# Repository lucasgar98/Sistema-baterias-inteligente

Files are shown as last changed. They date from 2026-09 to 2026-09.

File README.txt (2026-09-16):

================================================================================
  SISTEMA INTELIGENTE DE CARGA, DESCARGA Y DIAGNÓSTICO DE BATERÍAS (PROYECTO)
================================================================================

Este proyecto es una plataforma integrada de hardware y software diseñada para 
realizar ciclos de carga, descarga y caracterización de baterías de múltiples 
químicas (Li-Ion, Pb, NiMH). 

El sistema combina el control de potencia en tiempo real (MicroPython), una 
interfaz táctil física (LVGL v8 en CYD), visión por computadora para 
identificación de baterías (ESP32-CAM + pyzbar) y un backend de monitoreo y 
almacenamiento (FastAPI + SQLite + InfluxDB + MQTT) orquestado en Docker.

--------------------------------------------------------------------------------
1. ARQUITECTURA GENERAL Y FLUJO DE DATOS
--------------------------------------------------------------------------------

El flujo de información y control entre los componentes se organiza así:

   [ ESP32-CAM ] -------------( WiFi: Stream MJPEG )-------------> [ FASTAPI ]
         |                                                            |
     ( UART1 )                                                   ( Escribe a DB )
         |                                                            |
         v                                                            v
  [ ESP32 MASTER ]                                            [ SQLITE / INFLUX ]
    |          |
 ( UART2 )   ( I2C / PWM / ADC )
    |          |
    v          v
 [ CYD ]     [ SENSORES (INA219/NTC) y MOSFETS DE POTENCIA ]
 
* Comunicaciones clave:
  - ESP32 Master <-> Cheap Yellow Display (CYD): UART2 a 115200 baudios.
  - ESP32 Master <-> ESP32-CAM: UART1 a 115200 baudios.
  - ESP32 Master -> Sensor de Corriente (INA219): Bus I2C.
  - ESP32 Master -> MOSFETs de potencia: Señal digital PWM.
  - FastAPI (Servidor) <-> Broker MQTT (Mosquitto): Red local TCP.

--------------------------------------------------------------------------------
2. ESTRUCTURA DEL PROYECTO (Workspace)
--------------------------------------------------------------------------------

El repositorio se organiza de la siguiente manera:

/ (Raíz del proyecto)
|-- docker-compose.yml           <- Orquestador de servicios (Mosquitto, InfluxDB, API)
|-- README.txt                   <- Esta documentación principal
|
|-- backend/                     <- Servidor backend y panel de control web
|   |-- main.py                  <- API FastAPI, cliente MQTT, base de datos y lector QR
|   |-- dockerfile               <- Archivo de construcción de imagen Docker
|   |-- baterias.db              <- Base de datos SQLite (se genera sola al arrancar)
|   `-- frontend/                <- Código del dashboard web para PC
|       `-- index.html           <- Panel de monitoreo web interactivo
|
|-- firmware/                    <- Código fuente para los microcontroladores
|   |-- esp32_master/            <- Firmware del ESP32 Principal (MicroPython)
|   |   |-- main.py              # Lógica de potencia, control PWM y lectura de sensores
|   |   |-- config.json.template # Plantilla para configurar datos de red local
|   |   `-- legacy/              # Histórico: código viejo con botones analógicos
|   |       `-- legacy_main_buttons.py
|   |-- pantalla_cyd/            <- Interfaz gráfica táctil (ESP32 CYD con Arduino C++)
|   |   |-- pantalla_cyd.ino     # Inicialización, drivers de pantalla y lazo táctil
|   |   |-- ui.cpp               # Creación manual de pantallas, sliders y callbacks
|   |   `-- ui.h                 # Definición de variables de pantalla
|   |-- espcam/                  <- Cámara de lectura QR (ESP32-CAM con Arduino C++)
|   |   |-- espcam.ino           # Servidor web local de streaming MJPEG
|   |   `-- legacy/              # Histórico: lector de QR local serial
|   |       `-- legacy_serial_qr_reader.txt
|   `-- test_pantalla/           <- Diagnóstico de hardware táctil y colores
|       `-- test_pantalla.ino
|
|-- hardware/                    <- Archivos de diseño físico y circuital
|   |-- pcb_cargador/            <- Proyecto completo de la placa en KiCad
|   |-- ui_design/               <- Proyecto de prototipado original en EEZ Studio
|   |   |-- Lector Bateria.eez-project
|   |   `-- src/                 # Código LVGL exportado originalmente por EEZ
|   `-- 3d_print/                <- Modelos 3D de la carcasa (.3mf)
|
`-- documentacion/               <- Archivos de soporte y estudio
    |-- datasheets/              <- Fichas técnicas en PDF (MOSFETs, integrados)
    |-- BOM/                     <- Listas de materiales (formatos Excel y Word)
    |-- informes/                <- Reportes académicos y bitácora de cambios (PDF)
    `-- videos/                  <- Videos de demostración del circuito (MP4)

--------------------------------------------------------------------------------
3. EXPLICACIÓN DE COMPONENTES
--------------------------------------------------------------------------------

[ ESP32 Master ]
* Lazo de Corriente Constante: Genera PWM a 500 Hz para excitar los gates de los 
  MOSFETs. Aumenta o disminuye el ciclo de trabajo (+/- 20 pasos sobre 1000) 
  dependiendo de si la lectura de corriente está por debajo o por encima del 
  objetivo deseado (ej. 900 mA).
* Corrección de Tensión: Compensa dinámicamente las lecturas del voltaje en 
  función de la caída de tensión introducida por shunts y cables durante la 
  carga (-0.0001V por mA) y descarga (+0.00015V por mA).
* Filtro de Temperatura (EMA): Suaviza las muestras analógicas del NTC usando
  un promedio móvil exponencial con factor alpha = 0.08:
     T_filtrada = 0.08 * T_actual + 0.92 * T_anterior
* Seguridad Térmica: Si la temperatura supera los 45°C, detiene de inmediato 
  las salidas PWM y bloquea la operación. Se restablece automáticamente cuando 
  desciende por debajo de los 40°C.
* Lógica AUTO (Máquina de Estados): Corre la secuencia:
  Descarga inicial -> Espera enfriamiento -> Carga -> Espera -> Descarga de test.

[ Pantalla CYD (Cheap Yellow Display) ]
* Interfaz LVGL v8: Cuenta con navegación deslizable por pestañas (TileView):
  1. Principal: Mediciones en vivo, botones de acción rápida, QR activo.
  2. Parámetros: Selección de químicas y límites de voltaje/corriente.
  3. Red: Conexión WiFi/MQTT on-demand y teclado virtual para configuración.
* Integración UART: La pantalla no toma decisiones de potencia; le envía comandos 
  al Master (ej: "START_C", "SET_LIMITS:c,d,i") y recibe de éste cadenas JSON 
  con la telemetría en tiempo real.

[ ESP32-CAM ]
* Emisor de Video: Expone el stream MJPEG en la ruta http://[IP]/stream a 10 FPS 
  en resolución SVGA (800x600). Solicita datos WiFi al Master por Serial al iniciar.

[ Backend en Servidor (Docker FastAPI) ]
* Servidor y API REST: FastAPI orquesta la comunicación de todo el sistema. Expone 
  los endpoints para la interfaz web, el control remoto y la base de datos SQL.
* Decodificador QR en Servidor: El endpoint "/video_feed" capta el stream de la 
  cámara y aplica un pipeline de mejora de imagen (rotación, escala de grises, 
  contraste 2.0, umbrales de binarización y reescalado 2x) para decodificar el QR 
  con la librería "pyzbar" de forma robusta, previniendo crashes en el ESP32-CAM.
* Guardado de Telemetría: Consume las lecturas vía MQTT y las escribe tanto en 
  InfluxDB (series de tiempo en vivo) como en SQLite (ciclos cerrados y estadísticas).

--------------------------------------------------------------------------------
3.5 DETALLE DE SERVICIOS EN DOCKER Y PERSISTENCIA
--------------------------------------------------------------------------------

La infraestructura del backend se levanta en un entorno virtual aislado mediante 
Docker Compose, configurado en el archivo "docker-compose.yml". Se compone de 
tres servicios clave que cooperan en red:

1. Broker MQTT (Servicio "mosquitto")
   * Imagen: "eclipse-mosquitto:latest"
   * Puertos expuestos:
     - 1884 (externo, para conexión local TCP/IP) -> 1883 (interno de la red Docker)
     - 9001 (interno/externo, para WebSockets en caso de dashboards web directos)
   * Configuración: Carga el archivo "./mosquitto/config/mosquitto.conf". Está 
     configurado para permitir conexiones anónimas ("allow_anonymous true") para 
     simplificar el desarrollo y conexión de los microcontroladores.
   * Temas (Topics) MQTT del sistema:
     - "ESP32/telemetria": Cadenas de texto plano enviadas por el Master cada 3s 
       con formato "v:val,i:val,t:val,s:estado,qr:id,ah:val,p:perfil,vc:val,vd:val".
     - "ESP32/bateria_qr": Intercambio bidireccional del QR de la batería activa.
     - "ESP32/config_perfil": Consignas de límites de carga y descarga ("V_C:x.x,V_D:y.y").
     - "ESP32/comandos": Órdenes de control ("START_C", "START_D", "STOP_ALL").
     - "ESP32/espcam_ip": La cámara publica su IP para descubrimiento automático.
     - "ESP32/alerta_critica": Mensajes de error térmico ("SOBRETEMPERATURA:xxC").
   * Persistencia: Carpeta local "./mosquitto/data" montada en "/mosquitto/data".

2. Base de Datos Temporal (Servicio "influxdb")
   * Imagen: "influxdb:1.8" (versión 1.8 seleccionada por compatibilidad sencilla 
     y consultas HTTP directas sin autenticación por tokens complejos).
   * Puerto expuesto: 8086 (API de consulta y escritura).
   * Base de datos interna: "baterias_db".
   * Estructura de datos: Almacena la medición "telemetria_modulo".
     - Tags (indexados): "qr" (identificador de la batería).
     - Fields: "voltaje" (Float), "corriente" (Float), "temperatura" (Float).
   * Persistencia: Volumen local "./influxdb/data" mapeado a "/var/lib/influxdb" 
     para conservar las mediciones entre reinicios de los contenedores.

3. Servidor de Control y Base de Datos Relacional (Servicio "backend_baterias")
   * Imagen: Construida localmente con el "./backend/dockerfile". Usa Python 3.10-slim 
     e instala las librerías del sistema ("libzbar0" para lectura de QR) y de Python 
     ("fastapi", "uvicorn", "paho-mqtt", "sqlalchemy", "influxdb", "pyzbar", "pillow").
   * Puerto expuesto: 8000 (acceso a la interfaz web y endpoints).
   * Persistencia:
     - Mapea "./backend:/app" para permitir edición de código en vivo sin 
       reconstruir el contenedor.
     - Guarda el archivo de base de datos SQLite en "./backend/baterias.db".
   * Esquema SQLite (ORM SQLAlchemy):
     - Tabla "baterias_inventario" (Registro único de cada batería escaneada).
       Campos: "qr_id" (Texto, clave primaria), "fecha_registro" (Fecha/Hora), 
       "estado_general" (Texto).
     - Tabla "historial_ciclos" (Registro completo de cada carga/descarga terminada).
       Campos: "id" (Entero, auto-incremental), "qr_id" (Texto), "tipo_ciclo" (Texto), 
       "fecha_inicio" (Fecha/Hora), "fecha_fin" (Fecha/Hora), "voltaje_final" (Float), 
       "temp_maxima" (Float), "capacidad_ah" (Float), "soh_porcentaje" (Float), 
       "resistencia_interna" (Float).
   * Cliente MQTT Integrado: Al arrancar el backend en FastAPI, se inicia un hilo 
     secundario con el cliente MQTT ("paho-mqtt") que se suscribe a los tópicos del 
     Master. Éste procesa las tramas, calcula en tiempo real la capacidad acumulada 
     (integración por trapecios respecto al tiempo real) e identifica transiciones 
     de estado (ej. de REPOSO a CARGANDO) para abrir y cerrar ciclos en SQLite.
   * Servidor de Interfaz Web: Monta la carpeta "./backend/frontend" en la ruta 
     HTTP "/web" y sirve la web interactiva [index.html](file:///c:/Gonza/Carrera/Plan%202023/3er%20Año/Digitales%20IV/Proyecto%20bateria/backend/frontend/index.html) en la ruta raíz "/".

--------------------------------------------------------------------------------
4. MAPA DE CONEXIÓN DE PINES (PINOUT)
--------------------------------------------------------------------------------

+--------------------+---------------+---------------------+---------------+-----------------------------------+
| Dispositivo Origen | Pin de Salida | Dispositivo Destino | Pin de Entrada| Descripción / Protocolo           |
+--------------------+---------------+---------------------+---------------+-----------------------------------+
| ESP32 Master       | GPIO 18 (PWM) | MOSFET Canal N      | Gate          | Control de corriente de carga     |
| ESP32 Master       | GPIO 19 (PWM) | MOSFET Canal P      | Gate          | Control de corriente de descarga   |
| ESP32 Master       | GPIO 33 (ADC) | Divisor de Voltaje  | V_BAT         | Medición de voltaje de batería    |
| ESP32 Master       | GPIO 34 (ADC) | Divisor NTC         | Temperatura   | Medición de temperatura NTC       |
| ESP32 Master       | GPIO 21       | Sensor INA219       | SDA           | Bus I2C - Datos de corriente      |
| ESP32 Master       | GPIO 22       | Sensor INA219       | SCL           | Bus I2C - Reloj de corriente      |
| ESP32 Master       | GPIO 27 (TX1) | ESP32-CAM           | RX (U0R)      | UART1 - Envío configuración WiFi  |
| ESP32 Master       | GPIO 26 (RX1) | ESP32-CAM           | TX (U0T)      | UART1 - Recepción IP de cámara    |
| ESP32 Master       | GPIO 17 (TX2) | Pantalla CYD (CN1)  | RX (GPIO 22)  | UART2 - Transmisión de telemetría |
| ESP32 Master       | GPIO 16 (RX2) | Pantalla CYD (CN1)  | TX (GPIO 27)  | UART2 - Recepción de comandos     |
+--------------------+---------------+---------------------+---------------+-----------------------------------+

--------------------------------------------------------------------------------
5. GUÍA DE DESPLIEGUE Y PUESTA EN MARCHA
--------------------------------------------------------------------------------

A. Iniciar Infraestructura de Servidor (PC de laboratorio con Docker instalado):
   1. Colocarse en la raíz del proyecto (donde está "docker-compose.yml").
   2. Ejecutar el comando en la terminal:
         docker compose up --build -d
   3. Ingresar en el navegador web a: http://localhost:8000 para abrir la app.

B. Preparar ESP32 Master:
   1. Flashear la placa con MicroPython estable (v1.20 o superior).
   2. Subir el archivo de control "firmware/esp32_master/main.py".
   3. Copiar el archivo "config.json.template", renombrarlo como "config.json", 
      completar las credenciales WiFi y de MQTT de tu red y subirlo.
   4. Subir las librerías "ina219.py" y "umqtt/simple.py" a la placa.

C. Cargar Firmware de CYD y Cámara (Arduino IDE):
   * Pantalla CYD: Abrir "firmware/pantalla_cyd/pantalla_cyd.ino". 
     Librerías necesarias: "lvgl" (v8.x), "TFT_eSPI" (configurada con driver 
     y pines para la CYD), "XPT2046_Touchscreen" y "ArduinoJson".
   * ESP32-CAM: Abrir "firmware/espcam/espcam.ino". 
     Flashear seleccionando placa "AI Thinker ESP32-CAM".

--------------------------------------------------------------------------------
6. RESUMEN DE CAMBIOS REALIZADOS
--------------------------------------------------------------------------------

* Migración de Control Físico a Digital: Se removieron botones cableados en favor 
  de comandos por puerto serie desde la pantalla táctil.
* Procesamiento de QR en Servidor: Lector de QR se delegó al backend FastAPI 
  para evitar sobrecalentamientos y crashes en el ESP32-CAM.
* Módulos de Cálculo: Se añadió la estimación de Resistencia Interna (RI) 
  y el Porcentaje de Salud (SoH).
* Organización Limpia: Se clasificaron todos los archivos del repositorio en 
  firmware, hardware y documentación, dejando la raíz despejada y ordenada.
================================================================================

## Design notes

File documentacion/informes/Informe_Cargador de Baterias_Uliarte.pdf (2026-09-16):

## Asignatura: Técnicas Digitales 4

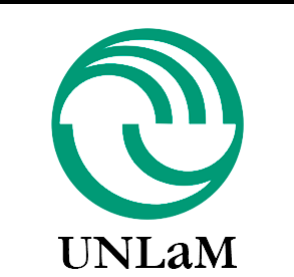
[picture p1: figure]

## Universidad Nacional de La Matanza

## INGENIERÍA ELECTRÓNICA

Profesor: ALEJANDRO FOURCADE, SAGARNA GUSTAVO HERNAN, DIEGO TURCONI

Trabajo Práctico N°: _-_ | Denominación: Cargador de Baterías NiMH _
_____ | _____ | ______
Grupo de Trabajo N°: _-_

Comisión: 01-3300

Ciclo Lectivo: 2025

Fecha de Entrega: | 24 / 7 / 25 | Nota del Grupo: ______________________
Fecha de Devolución: | / | / | Firma del Profesor: ___________________

Observaciones: ________________________________________________________ ______________________________________________________________________ ______________________________________________________________________

Integrantes | Nota Ind. | Nota Prom.
1- Uliarte Manuel
2-
3-
4-
5-

### INDICE

Análisis e Implementación de un Sistema de Carga/Descarga para Módulos de Baterías NiMH de Toyota Prius. 1

Análisis e Implementación de un Sistema de Carga/Descarga para Módulos de Baterías NiMH de Toyota Prius

I. Resumen

Este informe presenta un análisis de un sistema de carga y descarga, diseñado para módulos de baterías de Níquel-Hidruro Metálico (NiMH) de 7.2V, específicamente los utilizados en vehículos Toyota Prius. Se examinan los componentes de hardware, como los MOSFETs de potencia y el sensor INA219, así como la unidad de control basada en ESP32. Se explica la lógica de operación. Además, se describe la cadena de datos IoT, que abarca la transmisión inalámbrica desde el ESP32 a través de MQTT, el procesamiento en un servidor con Node-RED, el almacenamiento en una base de datos InfluxDB y la visualización en Grafana. El informe destaca las capacidades actuales del sistema, identifica limitaciones críticas, particularmente la ausencia de balanceo de celdas individuales, y ofrece recomendaciones detalladas para mejorar la seguridad, la fiabilidad y prolongar la vida útil de las baterías.

II. Introducción
Introducción a los Módulos de Baterías NiMH de Toyota Prius y sus Características.
Los vehículos híbridos Toyota Prius utilizan ampliamente módulos de baterías NiMH de 7.2V. Cada módulo consta típicamente de seis celdas NiMH de 1.2V conectadas en serie, proporcionando una tensión nominal de 7.2V y una capacidad típica de 6.5Ah. Estos módulos son reconocidos por su robustez y una vida útil probada de miles de ciclos y más de 10 años, especialmente cuando se gestionan adecuadamente dentro del sofisticado sistema de enfriamiento y gestión del vehículo. A diferencia de las baterías NiMH genéricas, estas están diseñadas para aplicaciones de alta potencia en vehículos híbridos, lo que implica características de rendimiento específicas que difieren significativamente de las baterías NiMH de consumo típico. Las fuentes de información indican explícitamente que no son una "química NiMH típica en ningún sentido”, poseyendo una "resistencia interna muy baja" y siendo capaces de una "tasa de descarga de 10C+". Esta distinción es fundamental para evaluar la idoneidad y el rendimiento del cargador. La necesidad de manejar las características robustas y específicas de estos módulos NiMH de grado automotriz, en lugar de las propiedades genéricas de las NiMH, es necesaria para optimizar su rendimiento y longevidad.

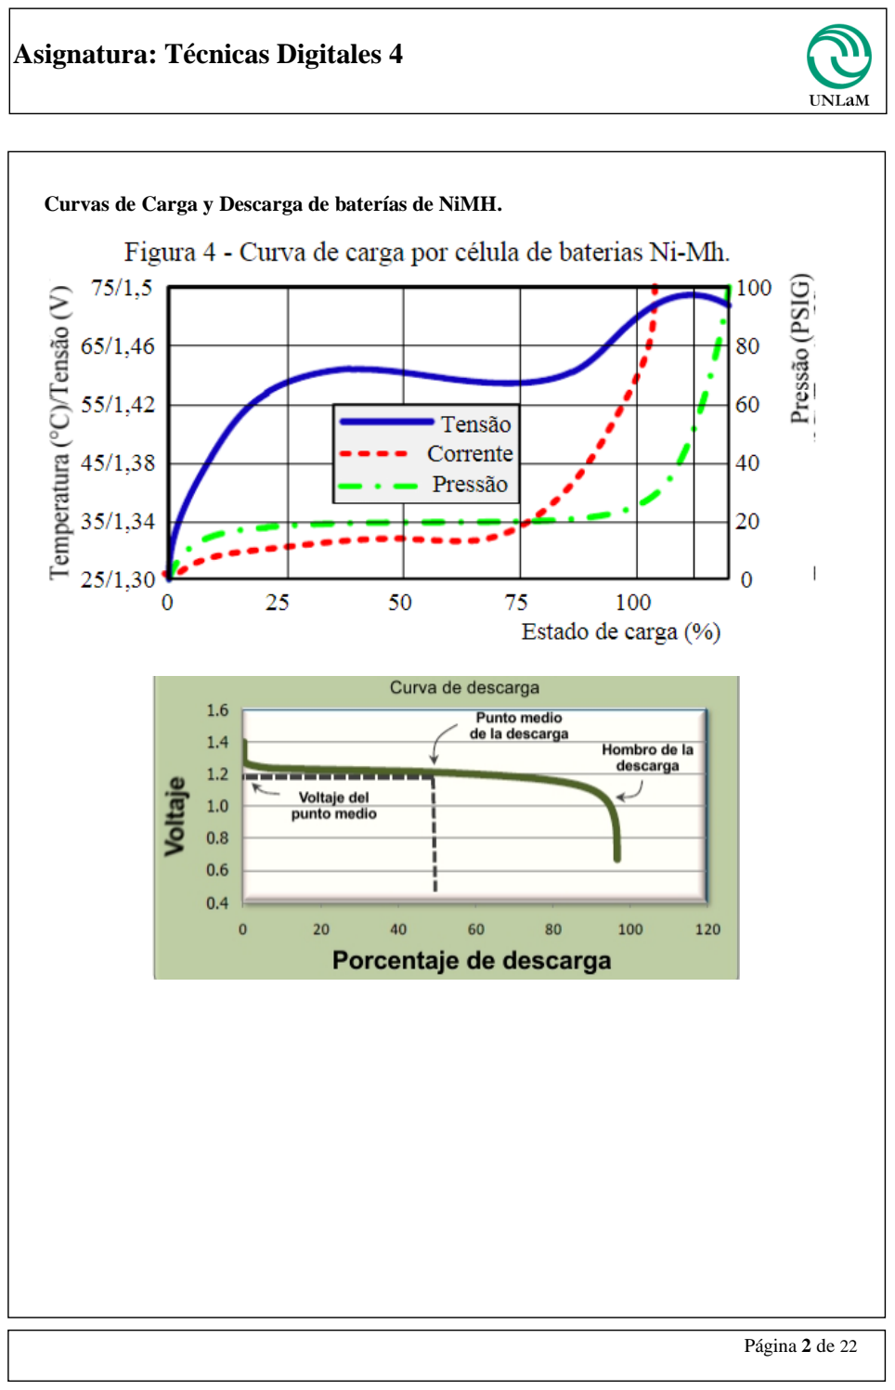
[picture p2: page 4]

Curvas de Carga y Descarga de baterías de NiMH.

Tipos de carga

| Carga según la capacidad | Tiempo típico de carga | Temperaturas máximas de carga | Método para terminar la carga
Carga Lenta | 0.1C | 14 Horas | 0°C a 45°C | Temporizador fijo. Sujeto a sobrecarga. Retirar la batería cuando esté cargada.
Carga Rápida | 0.3 a 0.5C | 4 Horas | 10°C a 45° | NDV ajustado a 10mV/celda, utiliza meseta de tensión, temperatura absoluta y temporizador. (A 0.3C, dT/dt no eleva suficientemente la temperatura para terminar la carga).
Carga Ultrarrápida | 1C | 1 hora o más | 10°C a 45° | NDV responde a ajustes más altos; usa dT/dt, meseta de voltaje, temperatura absoluta y temporizador.

NDV: Negative Delta Voltage
dT/dt: Cambio de temperatura con el tiempo.

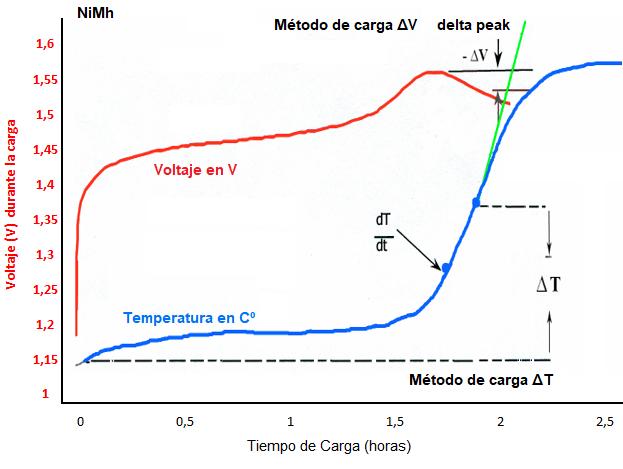
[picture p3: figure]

III. Visión General de la Arquitectura del Sistema

El sistema propuesto integra hardware y software para crear una solución de carga y descarga monitoreada para módulos de baterías NiMH. La arquitectura se puede dividir en varios bloques funcionales interconectados que gestionan el flujo de energía y datos.

Desglose Funcional de los Componentes Principales del Sistema
- Módulo de Batería: El componente central es el módulo de batería NiMH de 7.2V, que comprende seis celdas de 1.2V conectadas en serie.
- Etapa de Potencia: Esta sección se encarga del control de la energía hacia y desde el módulo de batería. Incluye MOSFETs canal P (2SJ294, Q1), canal N (2SK2806, Q2), un transistor de unión bipolar (BJT) como Q3 (BC548), componentes pasivos asociados para la polarización de los MOSFETs (resistencias R1, R3, R5 y R6), y por último una resistencia de potencia de 4.1Ω (R POT).

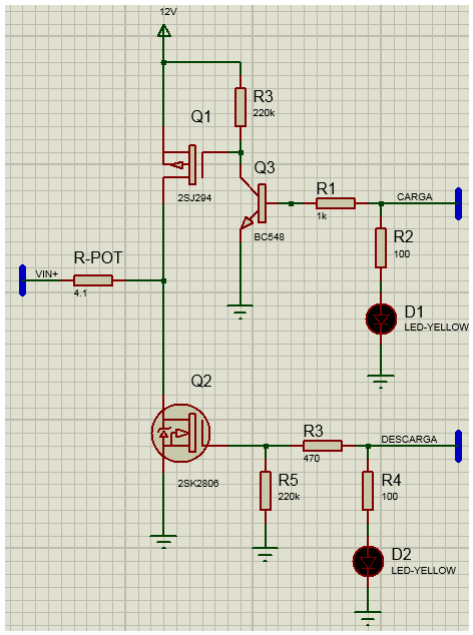
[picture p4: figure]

Medición de Tensión: Consta de un divisor resistivo (resistencias R7 y R8) conectado a la batería, junto a un capacitor para filtrar un poco el ruido (C3), y empleando el ADC del mismo ESP32 se logra medir la tensión de la batería.

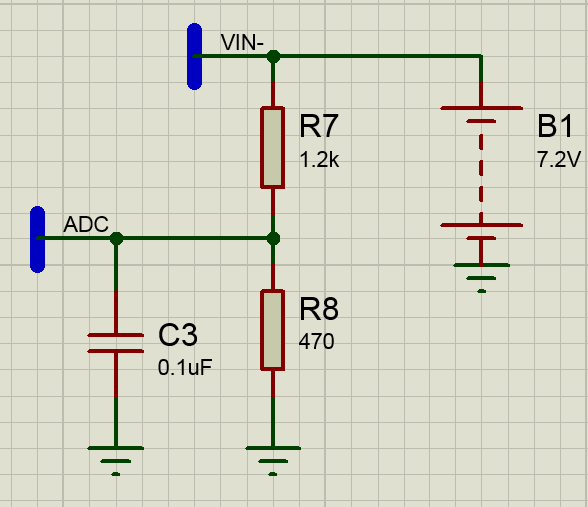
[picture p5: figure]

- Módulo de Detección de corriente (INA219): Un sensor INA219 se utiliza para medir la corriente del módulo de batería en tiempo real a través de una interfaz I2C. Este componente es fundamental para la monitorización precisa del estado de la batería.

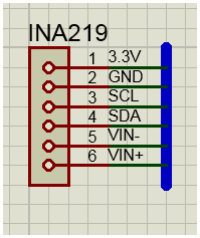
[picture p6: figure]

- Alimentación: Para alimentar tanto al ESP32 como al resto del circuito se emplea un LM7805 junto a sus capacitores de filtrado (C1 y C2).

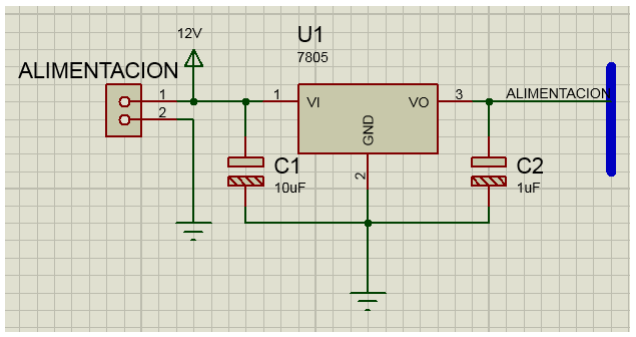
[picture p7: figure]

- Unidad de Control (ESP32): El microcontrolador ESP32 se encarga de la lógica de carga/descarga, lee los datos del sensor INA219 y gestiona la comunicación Wi-Fi/MQTT. Su capacidad para manejar tanto el control de hardware como la comunicación de red lo hace ideal para esta aplicación.

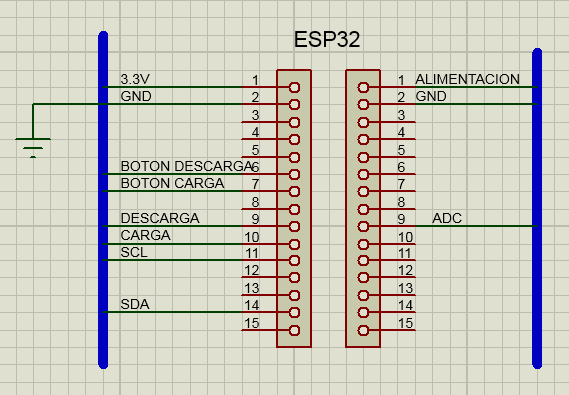
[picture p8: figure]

- Interfaz de Usuario: El sistema incorpora botones físicos para la selección del modo (J1, J2) y componentes para indicar cuándo estén funcionando (LESs D1, D2 y resistencias R2, R4) para proporcionar una indicación visual del estado al usuario.

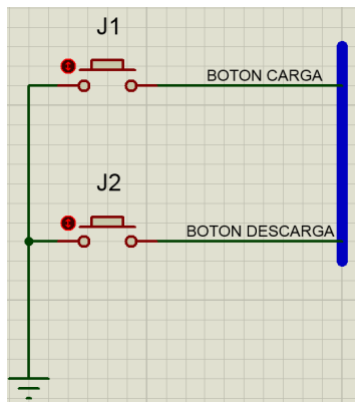
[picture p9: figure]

- Comunicación Inalámbrica (Wi-Fi/MQTT): El ESP32 transmite datos de monitoreo de la batería de forma inalámbrica a través de Wi-Fi utilizando el protocolo MQTT, permitiendo el monitoreo remoto.
- Servidor (Mosquitto/Node-RED/InfluxDB): En el lado del servidor, un broker Mosquitto recibe los mensajes MQTT. Node-RED procesa y decodifica estos mensajes, y luego los datos de series temporales se almacenan en una base de datos InfluxDB.
- Visualización (Grafana): Finalmente, Grafana se utiliza para presentar los datos de la batería almacenados en un formato gráfico intuitivo, tanto en tiempo real como histórico, facilitando el análisis del rendimiento de la batería.

La arquitectura propuesta establece un sistema de monitoreo de "bucle cerrado", lo que hace que se retroalimente de los datos de salida para ajustar su respuesta. La cadena de datos, que va desde el ESP32 hasta Grafana, sienta las bases para la futura integración de algoritmos de control avanzados y basados en datos. La inclusión de la adquisición de datos del sensor (INA219), la transmisión inalámbrica (ESP32 Wi-Fi/MQTT), el almacenamiento de datos (InfluxDB) y la visualización (Grafana) significa que los datos históricos de rendimiento del módulo de batería (tensión, corriente, ciclos de carga/descarga) se recopilarán y estarán disponibles continuamente. Si bien la lógica de control actual es reactiva (cortes de tensión fijo) e iniciada manualmente, está abierta a futuras mejorar para mejorar y automatizar el proceso. Por ejemplo, futuras mejoras podrían implicar modelos de inteligencia artificial/aprendizaje automático que analicen datos históricos para predecir la degradación de la batería, optimizar los perfiles de carga/descarga basados en el estado de salud real de la batería, o incluso automatizar los ciclos de reacondicionamiento. Esto transforma el sistema de un simple monitor/controlador en una plataforma de gestión de baterías inteligente y basada en datos.

IV. Diseño de Hardware y Análisis de Componentes

A. Etapa de Potencia: Circuitos de Carga y Descarga

Análisis de los MOSFETs (Q1, Q2) y sus principios operativos
La etapa de potencia del circuito es fundamental para la gestión controlada de la energía hacia y desde el módulo de batería. Esta etapa emplea MOSFETs (Transistores de Efecto de Campo Metal-Óxido-Semiconductor) como elementos de conmutación principales, complementados por un transistor de unión bipolar (BJT) para la lógica de control.
- Q1 (MOSFET de canal P, etiquetado como 2SJ294): Este MOSFET está configurado en la sección de carga. Su terminal de puerta (gate) es controlado por un BJT, Q3 (BC548) en el esquema. Cuando la señal "CARGA" del ESP32 (a través de R1) activa el BJT BC548, este tira la puerta del MOSFET de canal P a un nivel bajo, lo que a su vez enciende el MOSFET y permite el flujo de corriente desde la fuente de alimentación de 12V hacia la batería.
- Q2 (MOSFET de canal N, etiquetado como 2SK2806): Este MOSFET se encuentra en la sección de descarga. Cuando la señal "DESCARGA" del ESP32 eleva su puerta a un nivel alto (a través de R1), el MOSFET de canal N se enciende, permitiendo que la batería se descargue.

* Tensión Drenador-Fuente (VDS): El 2SK2806-01 tiene un VDS máximo de 30V. Esta clasificación proporciona un amplio margen para un módulo de batería de 7.2V, asegurando una operación robusta sin riesgo de ruptura.

* Corriente Continua de Drenador (ID): Está clasificado para ±35A. Esta alta capacidad de corriente es muy adecuada para las tasas de descarga potencialmente elevadas de los módulos NiMH de Toyota Prius, que se sabe que pueden entregar tasas de descarga de 10C+.

* Resistencia en Estado Activo Drenador-Fuente (RDS (on)): Típicamente entre 14-22 mΩ. Una baja resistencia en estado activo es fundamental para minimizar la disipación de potencia (generación de calor) dentro del MOSFET durante el flujo de corriente alta, mejorando así la eficiencia general del circuito de descarga.

* Tensión Umbral de Puerta (VGS(th)): Típicamente 1.5V. Este bajo umbral asegura que la señal lógica de 3.3V del ESP32 pueda conducir eficazmente el MOSFET a la saturación completa, minimizando las pérdidas por conducción.

Rol de los componentes pasivos asociados (resistencias R1, R2, R3, R4, R5, R6)
Las resistencias en el circuito desempeñan roles cruciales en la polarización, limitación de corriente y control de los MOSFETs y LEDs.
- R1 (1kΩ): Esta resistencias, en conjunto con el BC548 (Q3), forman la red de control para el MOSFET de carga de canal P. Y cuando se enciende, R1 limita la corriente del BJT para activar Q1.
- R2 (100Ω): Limita la corriente que fluye a través del LED amarillo D1, que indica el estado de carga.

- R3 (220kΩ): Permite polarizar el transistor Q1 actuando como "pull-up", forzando 12v en el Gate cuando Q3 este apagado.
- R4 (100Ω): Limita la corriente al LED amarillo D2, que indica el estado de descarga, de manera similar a R3 para el LED de carga.
- R5 (220kΩ): Sirve como una resistencia de "pull-down" en el Gate de Q2, asegurando que el MOSFET esté apagado de manera cuando la salida del ESP32 es baja o flotante, previniendo una descarga no intencionada.
- R6 (470Ω): Actúa como una resistencia limitadora de corriente para la "DESCARGA" del ESP32 hacia el Gate Q2.
- R Pot: 2 Resistencias de 8.2 Ω 7W en paralelo para permitir una resistencia de 4.1 Ω y 14W. Está se va a encargar de la disipación de la potencia del circuito para obtener los altos niveles de corriente.

Funcionalidad de los indicadores LED (D1, D2) y la fuente de alimentación de 12V
- D1 (LED) y D2 (LED): Estos LEDs sirven como indicadores visuales simples y directos. D1 se ilumina cuando el proceso de carga está activo, y D2 se ilumina cuando la descarga está en curso, proporcionando retroalimentación inmediata al usuario sobre el modo de operación del sistema.
B. Módulo de Detección: Monitor de Corriente y Tensión
Características y capacidades en profundidad del INA219, incluida su interfaz I2C
El INA219 es un monitor de corriente de lado alto y potencia, que integra una interfaz compatible con I2C para la comunicación digital. Monitorea la caída de tensión a través de una resistencia shunt (utilizada para determinar la corriente).
- Características Programables: El dispositivo ofrece tiempos de conversión y opciones de filtrado programables para las mediciones. Fundamentalmente, incluye un valor de calibración programable y un multiplicador interno, lo que permite lecturas directas en amperios y calcula la potencia en vatios, descargando estos cálculos del microcontrolador principal.
- Rango de Tensión: Está diseñado para detectar a través de shunts en buses que pueden variar de 0V a 26V, lo cual está bien dentro del rango de operación para un módulo de batería de 7.2V. Opera con una única fuente de alimentación entre +3V y +5.5V.
- Compatibilidad I2C/SMBus: El INA219 es compatible con los protocolos I2C y SMBus y cuenta con 16 direcciones programables, lo que permite una integración flexible en sistemas de bus I2C con múltiples dispositivos.
- Precisión: Presenta una alta precisión, con un error máximo del 1% en el rango de temperatura especificado.

Discusión de la calibración del INA219 para mediciones precisas de corriente.
El registro de calibración es fundamental para configurar la escala de los registros de corriente, asegurando que la salida digital corresponda directamente a la corriente medida en amperios y la potencia en vatios. Esta característica permite la calibración a nivel de sistema para compensar las tolerancias de la resistencia shunt y otros errores del sistema. El proceso de calibración implica definir parámetros del sistema (por ejemplo, tensión máximo del bus, tensión máximo del shunt, resistencia del shunt), calcular los valores apropiados del LSB (bit menos significativo) de corriente, y calcular el valor correspondiente del registro de calibración. Esta calibración meticulosa es esencial para lograr la alta precisión que el INA219 afirma.

Consideraciones para el filtrado y la protección de entrada
- Filtrado: El convertidor analógico-digital (ADC) interno del INA219 utiliza una arquitectura delta-sigma (ΔΣ), que proporciona una buena supresión de ruido inherente. Sin embargo, para transitorios que ocurren en o cerca de los armónicos de la frecuencia de muestreo de 500kHz (especialmente por encima de 1MHz), se recomienda un filtrado de entrada externo (utilizando resistencias en serie de bajo valor y capacitores cerámicos, típicamente de 0.1µF a 1.0µF) para mantener la precisión de la medición.
- Protección contra Sobrecarga: Las entradas del INA219 están especificadas para tolerar tensiones diferenciales de hasta 26V. En escenarios que involucran grandes corrientes o posibles retrocesos inductivos (por ejemplo, al desconectar cargas), se recomienda agregar resistencias en serie de 10Ω en cada pin de entrada para proteger contra una tensión excesiva, que de otro modo podría activar la protección ESD y potencialmente dañar el dispositivo.

Medición de Tensión.

- R7 (1.2 kΩ) y R8 (470 Ω): Forman un divisor resistivo para permitir bajar el nivel de tensión de la batería y poder leerlo con los pines del ESP32.
- C3 (0.1μF): Se encarga de filtrar un poco el ruido en la lectura de la tensión.
C. Unidad de Control: Microcontrolador ESP32
Rol del ESP32 en la gestión de ciclos de carga/descarga y adquisición de datos
El ESP32 actúa como la unidad central de procesamiento, orquestando todo el sistema. Lee datos de tensión, y corriente en tiempo real del INA219 a través del bus I2C, implementa la lógica de control de carga y descarga definida (por ejemplo, umbrales de tensión) y gestiona la comunicación inalámbrica (Wi-Fi y MQTT) para transmitir datos al servidor. Sus capacidades integradas de Wi-Fi y procesador de doble núcleo lo hacen altamente adecuado para este tipo de aplicación IoT que requiere tanto control local como conectividad de red.

Análisis de las asignaciones de pines GPIO del ESP32 para señales de control y comunicación I2C
- GPIOs para Botones: El esquema indica que "BOTON DESCARGA" está conectado al pin 16 del ESP32 y "BOTON CARGA" al pin 17. Estos pines se configuran como entradas digitales para detectar los comandos del usuario. Los botones están en configuración “pull-down", usando las resistencias internas del ESP32.

- GPIOs para Control de Carga/Descarga: "CARGA" se asigna al pin 19 del ESP32 y "DESCARGA" al pin 18. Estos pines se configuran como salidas digitales para controlar la circuitería de excitación de la puerta de los MOSFETs de carga y descarga.
- GPIOs para I2C (INA219): Las líneas de comunicación I2C, "SCL" y "SDA", están conectadas a los pines 21 y 22 del ESP32, respectivamente (Imagen 3). Si bien los pines I2C predeterminados para el ESP32 suelen ser GPIO 21 (SDA) y GPIO 22 (SCL), la funcionalidad I2C se puede configurar en varios otros GPIOs, lo que hace que la elección del usuario sea aceptable con la configuración de software adecuada.
- ADC para la lectura de Tensión: Se emplea el pin 33 que es utilizado para la lectura de tensión entregada por el divisor resistivo conectado a la batería.
- Fuente de Alimentación: Todo la plaqueta está alimentada por una fuente externa de 12V. Para alimentar el ESP32 se usan los 5V entregados por el LM7805. Además, aprovechando la salida de 3.3V del ESP32, se alimenta al INA219.
D. Interfaz de Usuario: Botones y Retroalimentación Visual
Análisis de los mecanismos de los botones de carga y descarga
Los botones físicos "BOTÓN CARGA" y "BOTÓN DESCARGA" buscan una interfaz de usuario simple e intuitivo para iniciar directamente los ciclos de carga o descarga. Estos son botones momentáneos que, al ser presionados, activan la acción correspondiente dentro del firmware del ESP32.

Interpretación de los indicadores LED para el estado del sistema
Los LEDs, D1 y D2, sirven como mecanismos de indicación visual. D1 se ilumina para indicar que el proceso de carga está activo, mientras que D2 indica que la descarga está en progreso.

E. PCB de la Placa

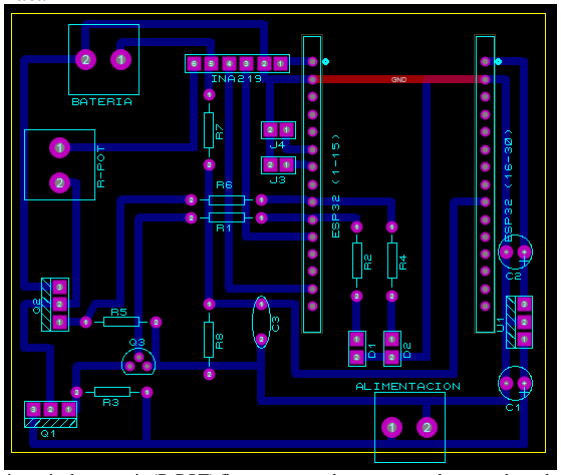
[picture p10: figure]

Aclaración: La resistencia de potencia (R-POT) figura como un borne, ya que, lo que se buscaba es la posibilidad de intercambiar la carga de la bateria en caso de desearlo.

V. Lógica Operativa y Principios de Gestión de Baterías
A. Lógica de Control de Carga
Explicación detallada de la iniciación y terminación de la carga basada en el umbral de 9V El proceso de carga está controlado para proteger la salud y longevidad de la batería.
- Iniciación de la Carga: El proceso de carga se inicia cuando el usuario presiona el botón "Carga", lo que indica al ESP32 que active la etapa de potencia de carga.
- Terminación de la Carga (Umbral de 9V): El circuito está diseñado para cortar automáticamente la carga si la tensión del módulo de batería supera los 9V. Para un módulo NiMH nominal de 7.2V (compuesto por seis celdas de 1.2V), esto se traduce en un promedio de 1.5V por celda (9V / 6 celdas). Esto actúa como un mecanismo primario de protección contra sobretensión, crítico para las baterías NiMH que tienen una tolerancia "moderada" a la sobrecarga.

Análisis de los efectos de la sobrecarga en la longevidad y seguridad de la batería NiMH La sobrecarga de las baterías NiMH conduce a la conversión del exceso de energía en calor, lo que acelera drásticamente la degradación química y reduce la vida útil general de la batería. Esto puede manifestarse como un aumento de la resistencia interna y la formación de cristales grandes que inhiben el rendimiento (efecto memoria). La sobrecarga prolongada, especialmente con corrientes de carga lenta inapropiadamente altas, puede dejar las baterías NiMH inoperables en un período muy corto, incluso si se sienten frías al tacto. Si bien las baterías NiMH son generalmente más tolerantes a la sobrecarga que las de Li-ion debido a las reacciones internas de recombinación de oxígeno e hidrógeno, la sobrecarga excesiva aún puede provocar una acumulación significativa de presión interna, lo que podría causar la ventilación de la celda (liberación de gases inflamables) o, en casos graves, la ruptura o explosión. Aunque las celdas NiMH pueden cargarse hasta un máximo de 9.6V (1.6V por celda), se decidió corta la carga al llegar a 9V para evitar sobrecargas.

B. Lógica de Control de Descarga
Explicación de la iniciación y terminación de la descarga basada en el umbral de 6V
El proceso de descarga también está cuidadosamente controlado para proteger la salud de la batería.
- Iniciación de la Descarga: El proceso de descarga se inicia cuando el usuario presiona el botón "Descarga", lo que indica al ESP32 que active la etapa de potencia de descarga.
- Terminación de la Descarga (Umbral de 6V): El circuito está diseñado para cortar automáticamente la descarga si la tensión del módulo de batería cae por debajo de 6V. Para un módulo NiMH nominal de 7.2V (seis celdas de 1.2V), esto corresponde a un promedio de 1.0V por celda (6V / 6 celdas). Este es una tensión estándar de fin de descarga para las baterías de níquel, crucial para prevenir la descarga profunda.

Análisis de los efectos de la descarga excesiva en la salud de la batería NiMH
La descarga de baterías de níquel más allá de su tensión de corte recomendado, particularmente bajo cargas pesadas, debe evitarse estrictamente. En paquetes de baterías de múltiples celdas conectadas en serie, las celdas individuales pueden tener capacidades o resistencias internas ligeramente diferentes. Si todo el paquete se descarga demasiado profundamente, la celda más débil puede alcanzar cero voltios y luego ser impulsada a una inversión de tensión (polaridad negativa) por las celdas más fuertes restantes. Esta condición conduce a la evolución de hidrógeno, acumulación de presión interna, agotamiento del electrolito, ventilación de la celda y, en última instancia, daño permanente o cortocircuito eléctrico de la celda afectada. La elección de un corte de descarga de 6V (1.0V/celda) es un enfoque seguro y conservador. Si bien algunas aplicaciones podrían permitir la descarga hasta 0.9V/celda, una tensión mínima de 1.0V/celda reduce significativamente el riesgo de inversión de celda individual dentro del módulo de 6 celdas, que es un modo de fallo crítico para los paquetes NiMH conectados en serie. Esta priorización de la salud de la batería sobre la extracción de cada último bit de energía contribuye a una mayor longevidad. La especificación de un corte de descarga de 6V por parte del usuario es un punto clave. La investigación establece que el fin de descarga típico para baterías de níquel es de 1V/celda, pero para tasas de descarga más altas, puede ser de 0.9V/celda. Sin embargo, la misma fuente advierte explícitamente contra la descarga más allá del tensión de corte para evitar la "inversión de celda" en celdas conectadas en serie, lo que puede causar daños permanentes. Dado que el módulo Prius es un paquete en serie de 6 celdas y las tensiones de las celdas individuales no se monitorean, establecer el corte en 1.0V/celda (6V para el módulo) proporciona un margen de seguridad mayor. Esto minimiza la posibilidad de que cualquier celda individual caiga significativamente por debajo de su límite seguro y sufra una inversión, incluso si hay ligeros desequilibrios dentro del módulo. Este enfoque conservador es una buena elección de diseño para la longevidad de la batería.
C. Características del Módulo de Batería NiMH de Toyota Prius
Especificaciones de los módulos NiMH de 7.2V (tensión nominal, recuento de celdas, capacidad típica, resistencia interna)
Como se ha aclarado, una "celda de 7.2V" de un Toyota Prius es en realidad un módulo que contiene seis celdas NiMH de 1.2V conectadas en serie. La tensión nominal del módulo es de 7.2V. La capacidad típica para módulos nuevos es de alrededor de 6.5Ah (Amperios-hora), mientras que las celdas reacondicionadas o de donación pueden variar de 3500-4000 mAh. Estos módulos son distintos de la química NiMH típica. Están diseñados para aplicaciones de vehículos híbridos de alta potencia, capaces de entregar tasas de descarga muy altas (tasa de descarga de 10C+) y exhibiendo una resistencia interna muy baja (aproximadamente 10 a 20 miliohmios por módulo). También pueden cargarse de forma segura en aproximadamente una hora.

La "muy baja resistencia interna" de los módulos NiMH de Toyota Prius es una característica crucial que los diferencia de las baterías NiMH genéricas (que típicamente tienen una resistencia interna más alta que las NiCd). Esta baja resistencia es primordial para las aplicaciones de vehículos híbridos que demandan altas corrientes de pulso. Las características generales de las baterías NiMH indican una resistencia interna típica de 200-300mΩ para un paquete de 6V. Sin embargo, la información específica sobre los módulos Prius destaca una "resistencia interna muy baja (~10 a 20 miliohmios en un módulo típico)". Esta es una diferencia significativa. Una alta resistencia interna en cualquier batería impacta significativamente su capacidad para entregar energía bajo carga, causando una caída de tensión y un corte prematuro.

Discusión del "efecto memoria" y la formación de cristales en las baterías NiMH
Las baterías NiMH, aunque menos susceptibles que las NiCd, aún sufren el "efecto memoria". Este fenómeno es causado principalmente por la formación de cristales grandes que inhiben el rendimiento en la placa positiva de níquel, un material compartido por las químicas NiCd y NiMH. Este crecimiento cristalino conduce a una depresión del tensión y una reducción de la capacidad utilizable. Para mitigar esto, es esencial una descarga completa periódica (a menudo denominada "ejercicio" o "reacondicionamiento") para las baterías NiMH, típicamente recomendada una vez cada tres meses, para romper estas formaciones cristalinas y restaurar la capacidad.

Importancia de la descarga completa periódica (ejercicio/reacondicionamiento) para el mantenimiento y la longevidad de la batería NiMH
Realizar regularmente un ciclo de descarga completo es necesario para las baterías NiMH para prevenir y revertir la acumulación de formaciones cristalinas, manteniendo así su capacidad y extendiendo su vida útil operativa. Sin embargo, es importante tener en cuenta que no se recomienda el ejercicio excesivo debido a la vida útil inherentemente más corta de la batería

NiMH en comparación con la NiCd. El ciclo de reacondicionamiento, que implica una descarga profunda a una tensión muy bajo (por ejemplo, 0.4V/celda) con una corriente reducida, es particularmente efectivo para romper las formaciones cristalinas más resistentes. Esta capacidad aborda directamente el "efecto memoria" y la formación de cristales, permitiendo al usuario realizar los ciclos de mantenimiento necesarios. Esto contribuye significativamente a prolongar la vida útil de los valiosos módulos NiMH. La investigación establece claramente que las baterías NiMH, a pesar de las mejoras con respecto a las NiCd, todavía sufren el "efecto memoria" debido a la formación de cristales y requieren una descarga completa periódica para mantener la capacidad y prolongar la vida útil. Por lo tanto, la capacidad de descarga de este circuito es una característica directa y necesaria para una gestión adecuada de las baterías NiMH, lo que mejora significativamente la longevidad y el rendimiento de los costosos módulos.

Análisis de las características de autodescarga de NiMH y los efectos de la temperatura Las baterías NiMH exhiben una tasa de autodescarga relativamente alta. Típicamente, pierden alrededor del 10% de su capacidad en las primeras 24 horas después de la carga, seguido de una disminución de aproximadamente el 10% por mes a partir de entonces. Esta tasa es aproximadamente un 50% más alta que la de las baterías NiCd. Las tasas de autodescarga en todas las químicas de baterías, incluidas las NiMH, aumentan significativamente con temperaturas más altas. Como regla general, la tasa se duplica con cada aumento de 10°C. Almacenar baterías NiMH a temperaturas elevadas u operarlas en condiciones ambientales cálidas (por ejemplo, a 45°C) acelera drásticamente la degradación, lo que lleva a una pérdida de capacidad irreversible y una reducción sustancial en la vida útil. La autodescarga y la degradación de las NiMH se aceleran significativamente por las altas temperaturas.

D. Consideraciones de Balanceo de Celdas para Paquetes Multi-Celda
Explicación de los diferentes tipos de desequilibrio de celdas de batería (Estado de Carga, capacidad total, impedancia)
El desequilibrio de celdas es un desafío inherente en los paquetes de baterías conectados en serie y puede manifestarse de varias maneras, cada una con implicaciones distintas para el rendimiento y la vida útil del paquete.
- Desequilibrio del Estado de Carga (SoC): Ocurre cuando las celdas individuales dentro de un paquete conectado en serie se cargan o descargan a diferentes niveles de SoC. Esto resulta directamente en tensión de circuito abierto (OCV) variables entre las celdas, con diferencias de tensión que se vuelven más pronunciadas en los extremos de la curva de carga/descarga. Este tipo de desequilibrio es común debido a variaciones en la autodescarga o la eficiencia de carga de las celdas.
- Diferencias de Capacidad Total: Surge cuando las celdas poseen inherentemente diferentes capacidades químicas totales (Q_MAX) debido a variaciones de fabricación o degradación desigual a lo largo del tiempo. Incluso si se descargan en la misma cantidad absoluta, las celdas con un Q_MAX más bajo alcanzarán un SoC químico más bajo, lo que provocará diferencias de OCV. Este desequilibrio es permanente y no se puede corregir mediante el balanceo de SoC.

- Diferencias de Impedancia: Se refiere a las variaciones en la resistencia interna (impedancia) entre las celdas individuales. Si bien estas diferencias no afectan el OCV, sí causan disparidades de tensión bajo carga (V = OCV + I*R). Una celda con mayor resistencia interna exhibirá una tensión más bajo durante la descarga y una tensión más alto durante la carga, lo que podría distorsionar los intentos de balanceo basados en el tensión. Las diferencias de impedancia pueden ser causadas por el envejecimiento, el uso o defectos de fabricación.

Impacto crítico del desequilibrio de celdas en el rendimiento, la seguridad y la vida útil del paquete de baterías de múltiples celdas
Confiar únicamente en la tensión total del módulo (7.2V) para la terminación de la carga y descarga en un paquete de celdas en serie es una limitación significativa que puede comprometer la seguridad y la longevidad de la batería. Las diferencias en el estado de carga o la capacidad entre las celdas individuales pueden llevar a que algunas celdas se sobrecarguen o se descarguen en exceso, incluso si la tensión total del módulo permanece dentro de los límites aceptables. Por ejemplo, durante la carga, una celda con menor capacidad o mayor resistencia interna alcanzará su tensión máximo antes que las demás. Si la carga continúa hasta que el módulo total alcance su umbral (9V), esa celda individual podría experimentar una sobrecarga severa, lo que provocaría un aumento de la temperatura, una degradación acelerada y posibles riesgos de seguridad, como la ventilación o la ruptura. De manera similar, durante la descarga, la celda más débil alcanzará su tensión mínimo antes que las demás. Si la descarga del módulo continúa hasta el umbral de 6V, esa celda podría ser impulsada a una inversión de polaridad por las celdas más fuertes, causando daños permanentes o un cortocircuito interno.

La ausencia de balanceo de celdas individuales en este sistema puede llevar a una degradación prematura de las celdas y a una reducción de la vida útil general del módulo de batería. La degradación de las celdas causada por el desequilibrio es un proceso autoacelerado: una vez que una celda tiene una capacidad menor, se expone a una tensión cada vez mayor durante la carga, lo que la degrada más rápido, reduciendo aún más su capacidad y cerrando un círculo vicioso. Si bien las baterías NiMH son relativamente tolerantes a la sobrecarga en comparación con las de iones de litio (debido a las reacciones internas de recombinación de oxígeno e hidrógeno que actúan como un "cortocircuito químico" interno), la sobrecarga a altas tasas aún puede causar un aumento de la presión dentro de la celda y crear una posibilidad de explosión o ventilación. Para las baterías NiMH, la autodescarga no aumenta monótonamente con el estado de carga, lo que significa que las celdas desequilibradas pueden tender a divergir aún más con el tiempo, exacerbando el problema.

VI. Cadena de Datos IoT y Visualización

La capacidad de monitorear y registrar datos de la batería en tiempo real es una característica fundamental de este sistema, que va más allá de la mera carga y descarga. Esta funcionalidad se logra a través de una cadena de datos IoT bien definida que abarca desde el sensor hasta la visualización final.

A. Comunicación Inalámbrica del ESP32 (Wi-Fi y MQTT)
El ESP32, con su módulo Wi-Fi integrado, actúa como el punto de origen de los datos en la cadena IoT. Una vez que el ESP32 adquiere los datos de tensión y corriente de la batería, los empaqueta y los transmite de forma inalámbrica a través de una red Wi-Fi local. Para la comunicación, el sistema utiliza el protocolo MQTT (Message Queuing Telemetry Transport). MQTT es un protocolo de mensajería ligero, ideal para dispositivos IoT con recursos limitados y redes con ancho de banda restringido, como el ESP32. Permite que el ESP32 publique los datos de la batería en un "broker" MQTT (en este caso, Mosquitto) en el servidor, utilizando un modelo de publicación/suscripción. Este enfoque separa el dispositivo que envía los datos (ESP32) de los dispositivos que los reciben, lo que aumenta la flexibilidad y la escalabilidad del sistema.
B. Procesamiento de Datos en el Servidor (Mosquitto y Node-RED)
Una vez que los datos de la batería son publicados por el ESP32 a través de MQTT, son recibidos por el broker Mosquitto, que actúa como un centro de mensajes centralizado en el servidor.

Después de recibir los mensajes MQTT, la computadora del servidor los procesa utilizando Node-RED, es una herramienta de programación basada en flujo que permite la interconexión de dispositivos de hardware, APIs y servicios en línea de manera visual. En este contexto, Node-RED se encarga de:

- Suscripción: Se suscribe a los "topics" MQTT donde el ESP32 publica los datos de la batería.
- Decodificación y Procesamiento: Una vez que recibe un mensaje, Node-RED decodifica el mensaje enviado por el ESP32. Esto puede implicar el análisis de la carga útil del mensaje (payload) para extraer los valores de tensión, corriente y cualquier otra información enviada.
- Transformación de Datos: Si es necesario, Node-RED puede transformar los datos en un formato adecuado para el almacenamiento en la base de datos InfluxDB.

Este enfoque modular y basado en flujos simplifica la lógica de procesamiento de datos en el lado del servidor, permitiendo una fácil modificación o expansión de la funcionalidad sin necesidad de reescribir código complejo.

C. Gestión de Bases de Datos (InfluxDB)
Una vez que Node-RED ha procesado y decodificado los datos de la batería, el siguiente paso en la cadena de datos es almacenarlos de manera eficiente. Para ello, el sistema utiliza InfluxDB, una base de datos de series temporales (TSDB) de código abierto. InfluxDB está optimizada para manejar datos con marca de tiempo, lo que la hace ideal para almacenar mediciones de sensores como la tensión y la corriente de la batería a lo largo del tiempo.

Las ventajas de usar InfluxDB en este sistema incluyen:

- Eficiencia para Datos de Series Temporales: Está diseñada para ingestión y consulta rápidas de datos de series temporales, lo que es crucial para el monitoreo en tiempo real.

- Escalabilidad: Puede manejar grandes volúmenes de datos a lo largo del tiempo, lo que permite el almacenamiento de un historial extenso del rendimiento de la batería.
- Optimización de Almacenamiento: Utiliza técnicas de compresión que reducen la huella de almacenamiento de los datos de series temporales.
D. Visualización de Datos (Grafana)
El paso final en la cadena de datos es la visualización, que permite al usuario interpretar y analizar el rendimiento de la batería a lo largo del tiempo. Grafana es una plataforma de código abierto para el análisis y monitoreo de datos que permite crear paneles de control interactivos y personalizables.

En este sistema, Grafana se conecta a la base de datos InfluxDB para recuperar los datos almacenados. El usuario puede configurar paneles de control para visualizar:

- Datos en Tiempo Real: Gráficos que muestran el tensión y la corriente actuales de la batería, proporcionando una visión inmediata del estado de carga/descarga.
- Datos Históricos: Tendencias de tensión y corriente a lo largo de horas, días o semanas, lo que permite el análisis del comportamiento de la batería a largo plazo y la identificación de patrones de rendimiento.
- Alertas: Grafana puede configurarse para generar alertas basadas en umbrales de datos, como una tensión de batería bajo o una corriente inusual, lo que notifica al usuario sobre condiciones críticas.

La combinación de ESP32, MQTT, Mosquitto, Node-RED, InfluxDB y Grafana crea una cadena de datos IoT completa. Esta cadena no solo permite el monitoreo en tiempo real, sino que también sienta las bases para el análisis de datos históricos, lo que podría habilitar futuras capacidades de mantenimiento predictivo y optimización de la batería. La presencia de esta detallada transmisión de datos permite la recopilación continua de información sobre el rendimiento del módulo de batería (tensión, corriente, ciclos de carga/descarga).

E. Diagrama de Bloques

VII. Evaluación del Rendimiento y Limitaciones
A. Rendimiento del Sistema bajo Condiciones Operativas Definidas
El sistema está diseñado buscando que la carga y descarga sean lo más controlada posible, complementado por una capacidad de monitoreo de datos.

Lectura
de Datos
(ESP32)

Transmisión
de Datos
(Mosquitto)

Almacenamiento
de Dato
(InfluxdB)

Visualización
de Datos
(Grafana)

Procesamiento
de Datos
Node-Red

- Control de Carga y Descarga: La implementación de umbrales de tensión (9V para carga, 6V para descarga) proporciona un control para proteger la batería contra la sobrecarga y la descarga excesiva. Estos límites son consistentes con las prácticas recomendadas para las baterías NiMH, buscando equilibrar la eficiencia de carga con la preservación de la vida útil de la batería.
- Monitoreo Preciso: El uso del sensor INA219 garantiza mediciones de corriente de alta precisión, que es necesario para una gestión eficaz de la batería.
- Capacidad IoT: La cadena de datos completa (ESP32 -> Wi-Fi/MQTT -> Mosquitto -> Node-RED -> InfluxDB -> Grafana) es una fortaleza significativa del sistema. Permite el monitoreo en tiempo real y el análisis histórico del rendimiento de la batería, lo que es invaluable para comprender su comportamiento a lo largo del tiempo y para fines de depuración o optimización.
- Interfaz de Usuario Sencilla: Los botones físicos y los indicadores LED proporcionan una interacción directa e intuitiva para el usuario, facilitando la operación del sistema.
B. Limitaciones Identificadas y Posibles Debilidades
A pesar de sus fortalezas, el sistema presenta varias limitaciones que podrían afectar la longevidad de la batería, la seguridad y el rendimiento general.
- Ausencia de Balanceo de Celdas Individuales: Esta es la limitación más crítica. El módulo de batería de 7.2V consta de seis celdas individuales de 1.2V conectadas en serie. El sistema actual solo monitorea la tensión total del módulo, no las tensiones de las celdas individuales. Esto hace que el sistema sea vulnerable a los efectos perjudiciales del desequilibrio de celdas, donde algunas celdas pueden sobrecargarse o descargarse en exceso, incluso si la tensión total del módulo está dentro de los límites seguros. El desequilibrio de celdas puede conducir a una degradación acelerada de las celdas más débiles, una reducción prematura de la capacidad total del módulo y un mayor riesgo de fallas de seguridad.
- Falta de Monitoreo de Temperatura Directa de la Batería: Las baterías NiMH son sensibles a las temperaturas elevadas, que pueden aumentar la autodescarga y acelerar la degradación. Sin esta retroalimentación, el sistema no puede tomar decisiones de carga/descarga adaptativas basadas en las condiciones térmicas de la batería, ni alertar sobre posibles sobrecalentamientos que podrían comprometer la seguridad o la vida útil.
- Falta de Detección de NDV para NiMH: Emplear el método de tensión delta negativa (NDV) resultaría más óptimo que simplemente cortar cuando se llegue a los 9V, ya que permitiría saber cuando están cargadas al 100%.
- Ausencia de Monitoreo del Estado de Salud (SoH) y Mantenimiento Predictivo: Aunque se recopilan datos históricos, el sistema no parece implementar algoritmos para evaluar el SoH de la batería o predecir su vida útil restante. Esto limita la capacidad del usuario para realizar un mantenimiento preventivo o planificar reemplazos de batería.

- Interacción Manual para Carga/Descarga: El inicio manual de los ciclos de carga y descarga, aunque simple, carece de la automatización que podría optimizar los ciclos de mantenimiento (ejercicio/reacondicionamiento) para las baterías NiMH.

VIII. Mejora y el Desarrollo Futuro

Para mejorar la seguridad, el rendimiento y la longevidad de los módulos de batería NiMH de gestionados por este sistema, se proponen las siguientes recomendaciones.

A. Mejoras de Hardware
- Integración de Sensores de Temperatura de la Batería: Incorporar uno o más sensores de temperatura (por ejemplo, termistores NTC) directamente en el módulo de batería. Esto proporcionaría datos térmicos cruciales para que el ESP32 ajuste dinámicamente los parámetros de carga y descarga, mitigue el estrés térmico y detecte condiciones de sobrecalentamiento, lo que es vital para la longevidad de las NiMH.
B. Mejoras de Software y Lógica de Control
- Lógica de Carga/Descarga Adaptativa Basada en Temperatura: Utilice los datos del sensor de temperatura de la batería para ajustar los umbrales de carga y descarga, o para pausar/reducir la corriente si la temperatura excede los límites seguros. Por ejemplo, la carga de NiMH a temperaturas elevadas reduce drásticamente la aceptación de carga y acelera la degradación.
- Algoritmos de Detección de NDV: Implemente algoritmos de detección de NDV que puedan compensar el ruido, el envejecimiento de las celdas y las variaciones de temperatura para una terminación de carga más precisa en las baterías NiMH.
- Automatización de Ciclos de Mantenimiento: Desarrolle una lógica en el ESP32 para automatizar los ciclos de "ejercicio" o "reacondicionamiento" periódicos para las baterías NiMH, según sea necesario (por ejemplo, una vez cada tres meses).
- Implementación de un Algoritmo de Estimación de SoC/SoH: Utilice los datos de tensión, corriente y temperatura (si se implementa) para desarrollar o integrar un algoritmo que estime con mayor precisión el SoC y el SoH del módulo de batería. Esto podría basarse en el conteo de Coulomb o en modelos más avanzados que tengan en cuenta la autodescarga y la degradación por envejecimiento.
C. Utilización de Datos y Análisis Avanzado
- Paneles de Control de Grafana Mejorados: Cree paneles de control en Grafana que visualicen el SoH, las tendencias de autodescarga y los desequilibrios de las celdas (si se implementa el balanceo). Esto proporcionaría información más procesable al usuario.
- Análisis de Datos para Mantenimiento Predictivo: Explore el uso de herramientas de análisis de datos (posiblemente con técnicas de aprendizaje automático en Node-RED o un servicio en la nube) para identificar patrones de degradación de la batería, predecir fallas y recomendar proactivamente el mantenimiento o el reemplazo.
D. Mejoras de Seguridad y Robustez
- Protección Térmica de Hardware: Considere la adición de un fusible térmico o un interruptor de corte por temperatura en la ruta de potencia para una capa de seguridad de hardware en caso de sobrecalentamiento severo que el control del ESP32 no pueda mitigar.
- Protección Eléctrica de Hardware: Incluir de un fusible eléctrico para que en caso de algún fallo o cortocircuito, que genere una corriente muy elevada, se proteja tanto al hardware, como a la batería.
- Protección contra Inversión de Polaridad: Aunque el circuito actual está diseñado para una conexión específica, la protección contra la inversión de polaridad en la entrada de la batería podría ser una adición valiosa para evitar daños en caso de una conexión incorrecta.

IX. Conclusiones

El sistema de carga y descarga trata de ser una solución para la gestión de módulos de baterías NiMH. Su arquitectura de hardware, que incorpora MOSFETs de potencia y el sensor INA219, junto con la versátil unidad de control ESP32, establece una base sólida para el control de energía. La lógica operativa proporciona protecciones contra la sobrecarga y la descarga excesiva. Además, la implementación de una cadena de datos IoT completa, desde la adquisición de sensores hasta la visualización en Grafana, es una característica que permite un monitoreo detallado y el análisis histórico del rendimiento de la batería.

Sin embargo, aun posee una limitación crítica: la ausencia de un sensor de temperatura para el módulo. Esto expone el sistema a riesgos, lo que puede conducir a una degradación prematura de la batería, una reducción de la vida útil y posibles problemas de seguridad, incluso si los umbrales de tensión a nivel de módulo se cumplen. Además, es necesario encontrar un método más óptimo para la medición de tensión, que se lo suficientemente sensible y estable para detectar el – V de 30mv.

Para concluir, el sistema planteado cumple su objetivo de cargar y descargar la batería, pero la implementación de los cambios propuestos anteriormente permitirían un control más preciso y además un menor desgaste de las baterías.

X Bibliografía

https://attachments.priuschat.com/attachment-files/2022/01/217491_Prius_Traction_battery_repair_summary_Part_1.pdf (https://attachments.priuschat.com/attachment-files/2022/01/217491_Prius_Traction_battery_repair_summary_Part_1.pdf) https://www.texashybridbatteries.com/question-4
https://randomnerdtutorials.com/esp32-influxdb/https://www.researchgate.net/publication/303959401_CONVERSOR_CA-CC_CUK_BASEADO_NA_CELULA_DE_COMUTACAO_DE_TRES_ESTADOS_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 (https://www.researchgate.net/publication/303959401_CONVERSOR_CA-CC_CUK_BASEADO_NA_CELULA_DE_COMUTACAO_DE_TRES_ESTADOS_COM_CORRECAO_DE_FATOR_DE_POTENCIA_APLICA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) https://todoproductividad.blogspot.com/2012/09/el-proceso-de-carga-y-descarga-de-las_9815.htmlhttps://www.cliqueapostilas.com/Content/apostilas/88023aec9e4422a3695dc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[captured%20website]%20WW.pdf (https://www.iz3mez.it/wp-content/library/ebook/Batteries%20In%20A%20Portable%20Wold%20%5bcaptured%20website%5d%20WW.pdf) https://www.luisllamas.es/arduino-transistor-mosfet/https://tahmidmc.blogspot.com/2012/12/low-side-mosfet-drive-circuits-and_23.htmlhttps://docs.micropython.org/en/l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

Link a drive:
https://drive.google.com/drive/folders/1QXZFtfiEudGasVtUDm5QPd3BNoxtcIIb?usp=sharing

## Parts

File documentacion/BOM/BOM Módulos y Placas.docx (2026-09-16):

Módulos y Placas

~~1x~~ ~~Fuente 12V~~

~~1x Módulo Step-~~~~down~~ ~~LM2596S~~

~~1x ESP32 (Versión de 30 pines, basado en los dos~~ ~~headers~~ ~~de 15 pines).~~

~~1x ESP32-CAM (Módulo de cámara para la lectura de los QR).~~

~~1x Pantalla CYD (Cheap Yellow~~ ~~Display~~~~).~~

~~1x Módulo INA219 (Sensor de corriente y voltaje).~~

Semiconductores

1x 2SJ294 (MOSFET Canal P) - Controla la rama de "+12V" para la CARGA.

1x 2SK2806 (MOSFET Canal N) - Controla la rama a GND para la DESCARGA.

1x BC548 (Transistor BJT NPN) - Actúa como driver para conmutar el MOSFET Canal P.

Resistencias

1x 1kΩ (R1) - Resistencia de base para el BC548.

1x 1.2kΩ (R7 superior) - Parte del divisor resistivo para leer el voltaje de la batería (BAT_V).

1x 100kΩ (R? inferior, figura como R7 también) - Divisor de tensión para el sensor NTC.

2x 220kΩ (R3 superior y R5) - Resistencias de Pull-up y Pull-down para asegurar el estado de los gates de los MOSFETs.

2x 470Ω (R8 en el divisor de tensión y R3 inferior en el gate del MOSFET N).

Capacitores

1x 0.1µF (C3 / 100nF) - Para filtrado en la lectura analógica de la batería.

Sensores

1x Termistor NTC 100K (Se conecta al puerto TEMP_SEN).

Conectores y Borneras

2x Tiras de pines hembra (Zócalos) de 15 pines (Para el ESP32).

1x Tira de pines hembra de 6 pines. (Para el INA219)

3x Conectores de 4 pines (headers JST Para CYD, ESP32-CAM y Resistencia de descarga).

1x Conectores de 2 pines (Sensor NTC)

2x Borneras a tornillo KF301 2 pines (Entradas +12V/GND y Batería).

1x Conector Jack DC Hembra

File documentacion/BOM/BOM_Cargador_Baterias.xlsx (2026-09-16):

Referencia | Descripción | Valor/Rating | Encapsulado | Notas
Q1 | MOSFET P-channel 2SJ294 | - | TO-220 | Gate driver con BJT. Sección carga
Q2 | MOSFET N-channel 2SK2806 | Id ±35A, Rds(on) 14–22 mΩ | TO-220 | Mosfet Logic Level. Sección descarga
Q3 | BJT BC548 (NPN) | 45V, 100mA | TO-92 | Driver gate Q1
R POT | Resistencia potencia (x2 en paralelo) | 8,2Ω / 7W | Axial | Equiv. 4.1Ω 14W
R1 | Resistencia | 1kΩ | TH | Control base BC548
R2 | Resistencia | 100Ω | TH | Limitadora LED D1
R3 | Resistencia | 220kΩ | TH | Pull-up Gate Q1
R4 | Resistencia | 100Ω | TH | Limitadora LED D2
R5 | Resistencia | 220kΩ | TH | Pull-down Gate Q2
R6 | Resistencia | 470Ω | TH | Limitadora señal ESP32 → Gate Q2
R7 | Resistencia | 1,2kΩ | TH | Divisor tensión
R8 | Resistencia | 470Ω | TH | Divisor tensión
INA219 | Sensor corriente INA219 | - | - | Interfaz I2C
U1 | Regulador LM7805 | 5V | TO-220 | Entrada 12V, salida 5V
C1 | Capacitor electrolítico | 10µF | Radial | Filtro entrada 7805
C2 | Capacitor electrolítico | 1µF | Radial | Filtro salida 7805
C3 | Capacitor cerámico | 0,1µF | TH | Filtro divisor tensión
D1 | LED amarillo indicador | 2V/20mA | 5mm | Indicador carga
D2 | LED amarillo indicador | 2V/20mA | 5mm | Indicador descarga
J1 | Pulsador | - | Tactile 6x6mm | Botón carga
J2 | Pulsador | - | Tactile 6x6mm | Botón descarga
CON_BAT | Bornera 2p | - | Terminal block | Conexión módulo batería
CON_R-POT | Bornera 2p | - | Terminal block | Conexión Resistencias de Potencia
CON_12V | Bornera 2p | - | Terminal block | Conexión Alimentación
 | Bornera 2p hembra 12V | - | Terminal block / Jack DC | Conexión fuente

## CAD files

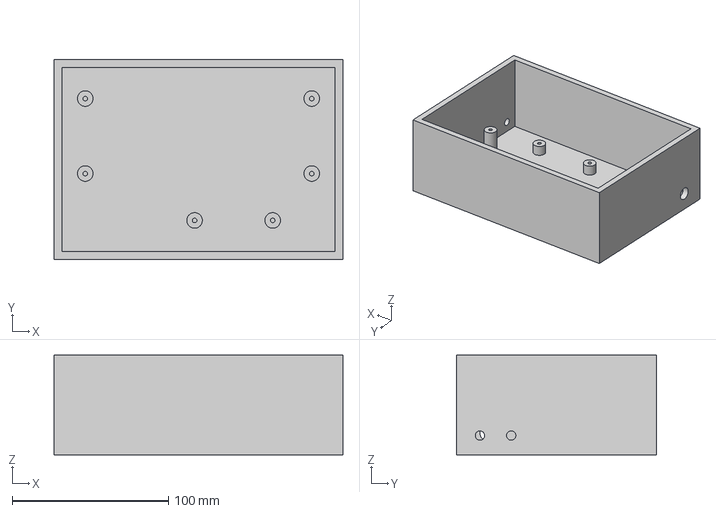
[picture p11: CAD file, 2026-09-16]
hardware/3d_print/Cuerpo1.3mf
185.0 x 128.0 x 64.0 mm

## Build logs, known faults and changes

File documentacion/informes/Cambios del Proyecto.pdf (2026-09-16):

Proyecto: Cargador de Baterías

### Mejoras propuestas:

- Añadir la medición de la temperatura de la batería. Por motivos de seguridad, además de funcionar como método para realizar el corte de carga.
- Añadir una cámara para escanear el código QR de las baterías que indica el código de serie. Poder identificar individualmente las baterías en la base de datos para facilitar su registro.
- Implementar una Raspberry. Con el objetivo de cargarle el stack IOT.
- Añadir modo de carga/descarga lenta y rápida.
- Cambiar la secuencia de medición de la tensión. El método anterior producía errores de lectura que eran compensados por código. El nuevo método busca eliminar/reducir la

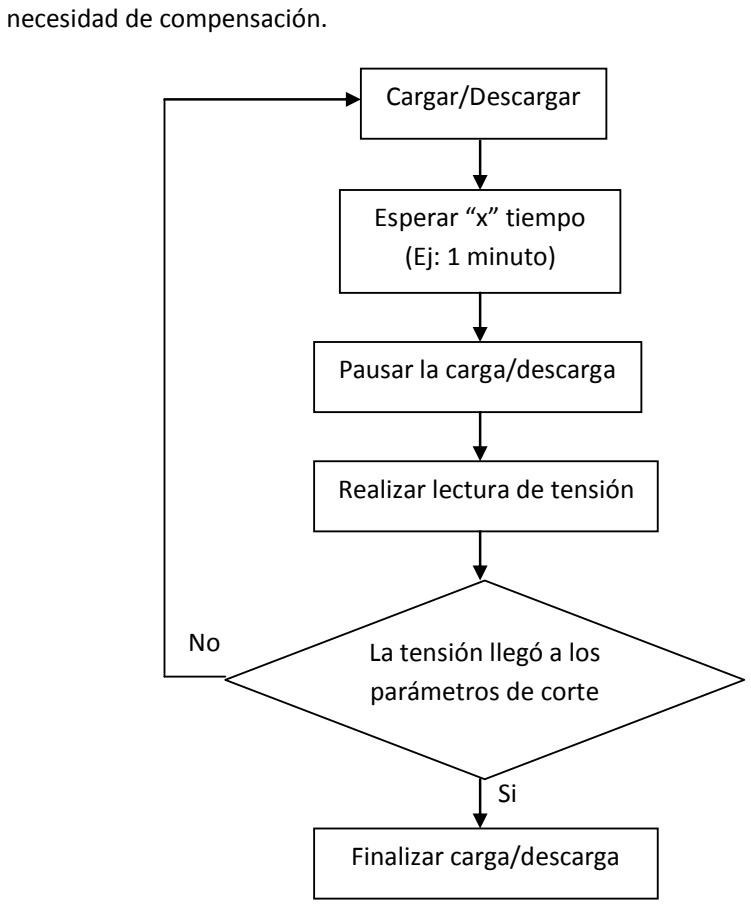
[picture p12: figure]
necesidad de compensación.; Cargar/Descargar; Esperar “x” tiempo (Ej: 1 minuto); Pausar la carga/descarga; Realizar lectura de tensión; La tensión llegó a los parámetros de corte; Finalizar carga/descarga

### Ciruito actual:

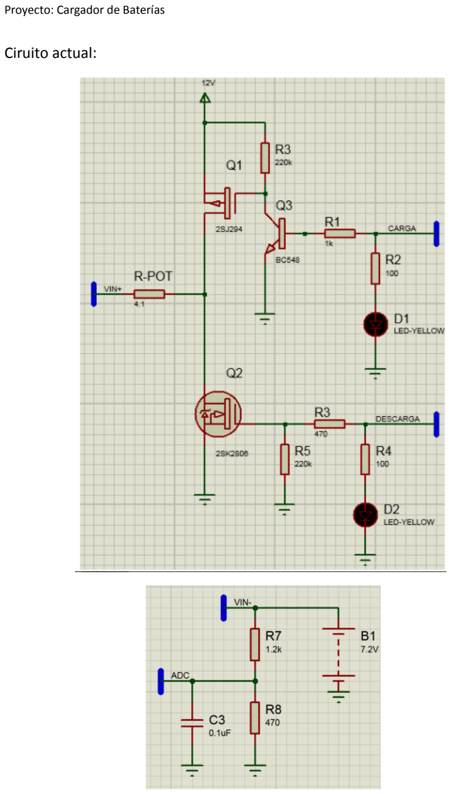
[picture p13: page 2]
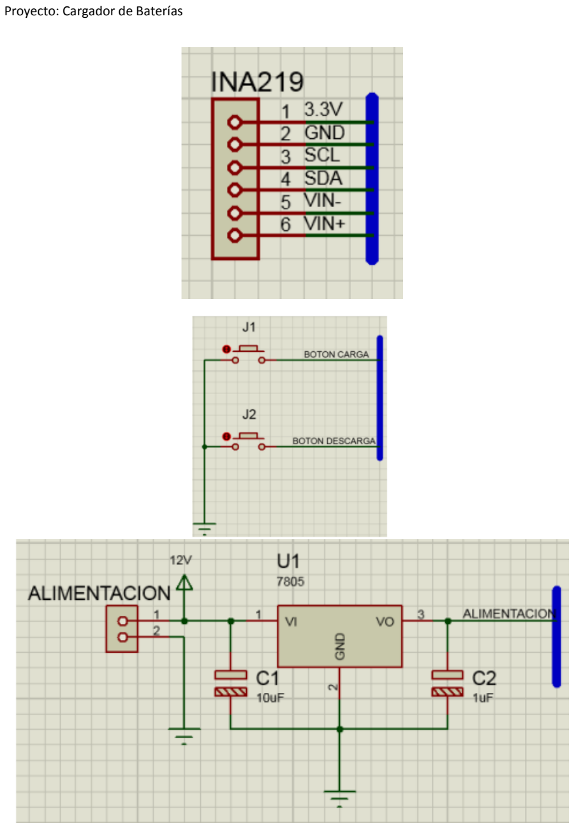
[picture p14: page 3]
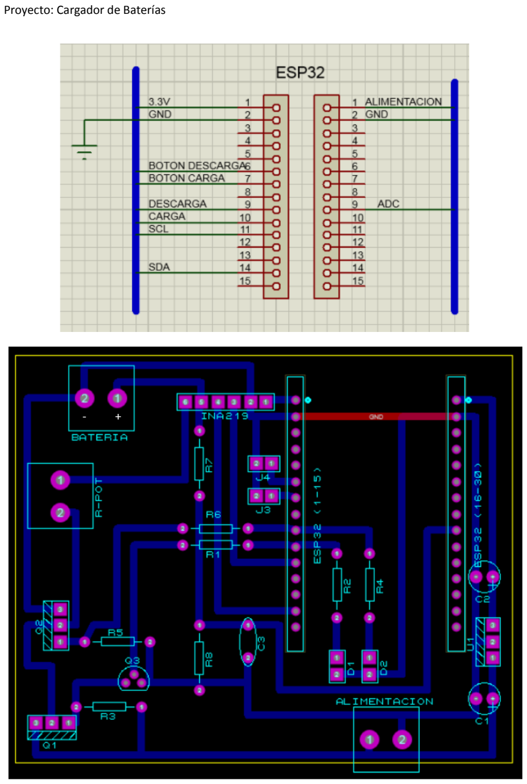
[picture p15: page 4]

- +

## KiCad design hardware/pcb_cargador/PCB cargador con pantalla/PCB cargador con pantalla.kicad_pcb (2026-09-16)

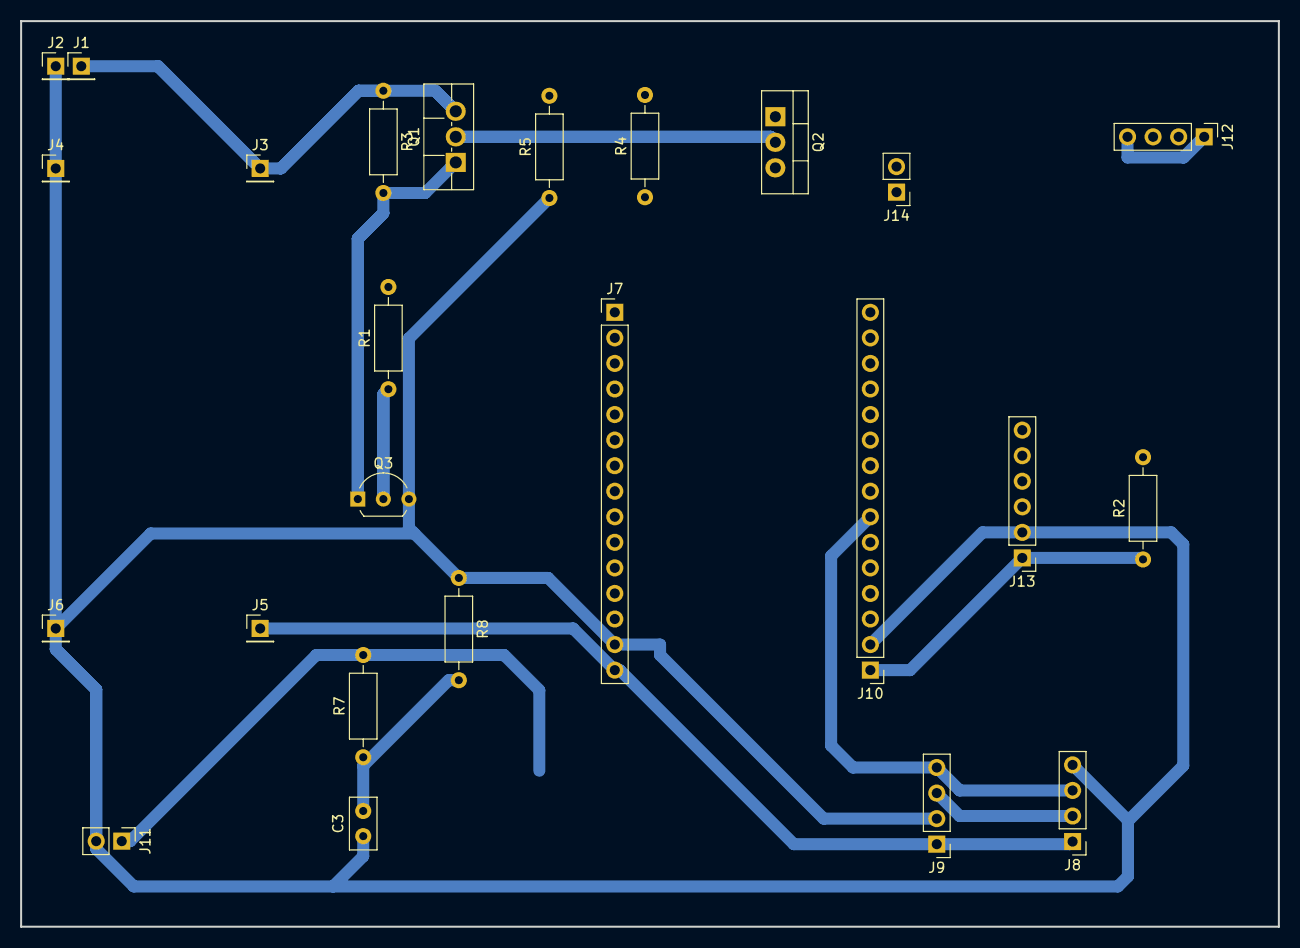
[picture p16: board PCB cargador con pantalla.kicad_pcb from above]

Board: 2 copper layers, 125.0 x 90.0 mm, 25 parts (0 on the bottom side), 18 nets.

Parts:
C3: 0.1; C_Disc_D5.0mm_W2.5mm_P2.50mm
J1, J3: 12V; PinHeader_1x01_P2.54mm_Vertical
J2, J4, J6: GND; PinHeader_1x01_P2.54mm_Vertical
J5: 5V; PinHeader_1x01_P2.54mm_Vertical
J7: SIDE_B_ESP32; PinHeader_1x15_P2.54mm_Vertical
J8: CONECTOR_CYD; PinHeader_1x04_P2.54mm_Vertical
J9: CONECTOR_ESPCAM; PinHeader_1x04_P2.54mm_Vertical
J10: SIDE_A_ESP32; PinHeader_1x15_P2.54mm_Vertical
J11: BATTERY; PinHeader_1x02_P2.54mm_Vertical
J12: LOAD; PinHeader_1x04_P2.54mm_Vertical
J13: CONNECTOR_INA219; PinHeader_1x06_P2.54mm_Vertical
J14: TEMP_SEN; PinHeader_1x02_P2.54mm_Vertical
Q1: 2SJ294; TO-220F-3_Vertical
Q2: 2SK2806; TO-220-3_Vertical
Q3: BC548; TO-92L_Inline_Wide
R1: 1K; R_Axial_DIN0207_L6.3mm_D2.5mm_P10.16mm_Horizontal
R2: 100k; R_Axial_DIN0207_L6.3mm_D2.5mm_P10.16mm_Horizontal
R3, R5: 220k; R_Axial_DIN0207_L6.3mm_D2.5mm_P10.16mm_Horizontal
R4, R8: 470; R_Axial_DIN0207_L6.3mm_D2.5mm_P10.16mm_Horizontal
R7: 1k2; R_Axial_DIN0207_L6.3mm_D2.5mm_P10.16mm_Horizontal

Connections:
+5V: J5.1, J7.15, J8.1, J9.1
+12V: J1.1, J3.1, Q1.3, R3.1
/3.3V: J10.1, J13.1, R2.1
/D21: J10.11, J13.3
/D22: J10.14, J13.4
/V+: J11.1, J13.5, R7.2
/VIN+: J12.1, J12.4, J13.6
BAT_V: C3.2, J7.7, R7.1, R8.2
CARGA: J10.10, R1.2
DESCARGA: J10.9, R4.1
GND: C3.1, J2.1, J4.1, J6.1, J7.14, J8.4, J9.2, J10.2, J11.2, J13.2, J14.2, Q2.3, Q3.3, R5.1, R8.1
NTC100K_V: J7.4, J14.1, R2.2
unnamed: J12.2, J12.3, Q1.2, Q2.2
unnamed: Q1.1, Q3.1, R3.2
unnamed: Q2.1, R4.2, R5.2
unnamed: Q3.2, R1.1
RX_CYD: J7.9, J8.3, J9.4, J10.7
RX_ESPCAM: J7.10, J8.2, J9.3, J10.6

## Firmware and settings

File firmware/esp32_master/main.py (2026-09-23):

from machine import Pin, I2C, PWM, ADC, UART
from ina219 import INA219  # Módulo para leer el sensor de corriente INA219 (no está incluido en la carpeta esp32_master)
from time import sleep, ticks_ms, ticks_diff
import network
import math
import json  # Módulo para trabajar con archivos JSON
from umqtt.simple import MQTTClient  # Módulo para trabajar con MQTT (no está incluido en la carpeta esp32_master)

# ========================
# LECTURA DE CONFIGURACIÓN (Wi-Fi y MQTT)
# ========================
# Función que carga la configuración WiFi y MQTT que se encuentra en el archivo config.json
# Si no encuentra el archivo, retorna parámetros de configuración por defecto
def cargar_config():
    try:
        # Utilizamos la estructura with...as, la cual simplifica la gestión de recursos que deben
        # ser limpiados después de su uso. En este caso, nos permite abrir el archivo sin necesidad
        # de cerrarlo manualmente
        with open('config.json', 'r') as f:
            return json.load(f)  # Convierte el JSON a un diccionario de Python
    except:
        # Retornamos credenciales por defecto en caso de un error al abrir el archivo
        return {"ssid": "Proyecto", "pass": "ligafederal", "mqtt": "10.187.200.199"}

config_actual = cargar_config()
# ========= CREDENCIALES DE WIFI y MQTT ===========
# Credenciales de la red WiFi
WIFI_SSID = config_actual["ssid"]  # SSID
WIFI_PASSWORD = config_actual["pass"]  # Contraseña
# Credenciales del broker MQTT
MQTT_BROKER = config_actual["mqtt"]  # Dirección IP del broker MQTT
MQTT_USER = config_actual.get("m_user", "admin")  # Usuario ("admin" si no existe en config.json)
MQTT_PASS = config_actual.get("m_pass", "baterias2026")  # Contraseña ("baterias2026 si no existe en config.json")

# ========================
# CONFIGURACIÓN GENERAL 
# ========================
# ========== PARÁMETROS DE CONFIGURACIÓN DE MQTT ===========
MQTT_PORT = 1884  # Puerto
MQTT_CLIENT_ID = 'Gonza'  # ID del cliente
# Tópico para enviar los valores actuales de tensión y corriente de la batería, junto con parámetros adicionales
# Las cadenas de texto son enviadas por el maestro cada 3 segundos, con el siguiente formato: "v:val,i:val,t:val,s:estado,qr:id,ah:val,p:perfil,vc:val,vd:val"
MQTT_TOPIC_TELEMETRY = 'ESP32/telemetria'
# Tema para el intercambio bidireccional del QR de la batería activa
MQTT_TOPIC_QR = 'ESP32/bateria_qr'
# Tema para enviar mensajes de error debido a exceso de temperatura ("SOBRETEMPERATURA:xxC")
MQTT_TOPIC_ALERTA = 'ESP32/alerta_critica'
# Tópico para publicar los límites de carga y descarga de la batería (V_C:x.x,V_D:y.y")
MQTT_TOPIC_CONFIG = 'ESP32/config_perfil' # Nuevo: Recibir perfiles
# Tópico para enviar comandos para que la batería se cargue ("START_C") o se descargue ("START_D"), así como también para frenar el sistema ("STOP_ALL")
MQTT_TOPIC_COMANDOS = 'ESP32/comandos'     # Nuevo: Recibir comandos desde Web

# Limites de Operación Segura (NiMH 7.2V por defecto)
TEMP_MAXIMA_SEGURA = 45.0  # Temperatura máxima (45°C)
VOLTAJE_CORTE_CARGA = 9.0  # Tensión máxima de carga (9 V)
VOLTAJE_CORTE_DESCARGA = 6.0  # Tensión mínima de descarga (6 V)
CORRIENTE_OBJETIVO = 900  # Corriente de carga (900 mA)
# Parámetros del ADC
V_REF = 1100.0  # Tensión de referencia del ADC integrado del ESP32 (1100 mV)
K = 0.25  # Constante de atenuación del ADC

# Diccionario que almacena los umbrales de carga y descarga para cada tipo de batería
PERFILES_LOCALES = {
    "LI-ION-2S": (8.4, 6.0),  # 2S de iones de litio
    "LI-ION-3S": (12.6, 9.0),  # 3S de iones de litio
    "PB-12V": (14.4, 11.0),  # Plomo ácido de 12 V
    "NiMH-7.2V": (9.0, 6.0)  # Níquel-metalhidruro de 7.2 V
}
TIEMPO_DESCANSO_MS = 15 * 60 * 1000 # Tiempo de descanso (15 minutos)

# ========================
# CONFIGURACIÓN DE HARDWARE
# ========================
# Configuramos los pines GPIO21 y GPIO22 como pines SCL y SDA del bus I2C0
i2c = I2C(0, scl=Pin(21), sda=Pin(22))
# Inicializamos el sensor de corriente INA219, vinculándolo al bus I2C0
ina = INA219(i2c)
ina.configure()
# Configuramos los pines GPIO18 y GPIO19 como salidas PWM a 500 Hz conectadas al circuito de
# carga y descarga formado por transistores MOSFET
pin_Carga = PWM(Pin(18, Pin.OUT), freq=500, duty=0)  # Pin para la carga (GPIO18)
pin_Descarga = PWM(Pin(19, Pin.OUT), freq=500, duty=0)  # Pin para descarga (GPIO19)
# Configuramos el pin GPIO33 como entrada analógica para medir la tensión de la batería
adc_bat = ADC(Pin(33))
adc_bat.width(ADC.WIDTH_12BIT) # Resolución de 12 bits
adc_bat.atten(ADC.ATTN_11DB)  # Atenuación de 11 dB para medir tensiones mayores a 1100 mV (Vref)
# Configuramos el pin GPIO34 como entrada analógica para medir la tensión del termistor NTC, lo cual nos permite obtener la temperatura
adc_temp = ADC(Pin(34))
adc_temp.width(ADC.WIDTH_12BIT)  # Resolución de 12 bits
adc_temp.atten(ADC.ATTN_11DB)  # Atenuación de 11 dB
# Inicializamos los UARTs 1 y 2 a una velocidad de 115200 baudios
uart_cam = UART(1, baudrate=115200, tx=27, rx=26) # UART1 para la comunicación con el módulo ESP-CAM (TX1 = GPIO27, RX1 = GPIO26)
uart_tft = UART(2, baudrate=115200, tx=17, rx=16) # UART2 para la comunicación con la pantalla CYD (TX2 = GPIO17, RX2 = GPIO16)

# ========================
# ESTADOS DEL SISTEMA
# ========================
# ==== Variables bandera ====
estado_Carga = False
estado_Descarga = False
alerta_termica = False
wifi_conectado = False
estado_anterior_activo = False  # Indica si la batería estuvo inactiva o no (se usa para el cálculo de la capacidad)
modo_auto = False  # Indica si está activado el modo auto (uno o varios ciclos completos de carga/descarga)
# ==== Variables asociadas con la batería ====
bateria_qr_actual = "NINGUNA"  # Variable que guarda el QR de la batería
perfil_actual = "NiMH-7.2V"  # Tipo de batería
capacidad_ah = 0.0  # Capacidad (en Ah)
ultimo_calculo_ah = ticks_ms()  # Instante de tiempo en el que se hizo por última vez el cálculo de la capacidad
inicio_espera = 0  # Instante de tiempo para iniciar una demora de 15 minutos luego de la carga o la descarga
nivelPWM = 0  # Almacena el ciclo de actividad como un número entre 0 y 1023, el cual se pasa como argumento del método PWM.duty()
# Variable que guarda el estado del sistema en modo auto. Los posibles estados son IDLE, DESC1, WAIT1, CARGA, WAIT2 y DESC2
paso_auto = "IDLE"
# Variable que almacena la temperatura filtrada
temperatura_filtrada = None
# ==== Variables para la comunicación
buffer_uart_tft = ""  # Buffer que almacena los caracteres recibidos de la pantalla a través del UART2 (en formato string)
buffer_uart_cam = ""  # Buffer para guardar los caracteres recibidos de la cámara
espcam_ip_actual = "NINGUNA"  # Almacena la IP de la cámara
mqtt_client = None  # Objeto o instancia de la clase MQTTClient para configurar MQTT

# ========================
# FUNCIONES AUXILIARES
# ========================
# Función que establece la conexión con la red WiFi
def conectar_wifi():
    global wifi_conectado
    try:
        print(f"Conectando a {WIFI_SSID}...")
        # Creamos una instancia de la clase WLAN, seleccionando la interfaz estación
        wlan = network.WLAN(network.STA_IF)
        # Activamos la interfaz de red
        wlan.active(True)
        # Establecemos la conexión al punto de acceso
        wlan.connect(WIFI_SSID, WIFI_PASSWORD)
        intentos = 0  # Número de reintentos de conexión al AP
        # Intentamos conectarnos al AP con un número máximo de 20 intentos
        while not wlan.isconnected() and intentos < 20:
            sleep(0.5)  # Demora de 500 ms
            intentos += 1
        if wlan.isconnected():
            # Si el ESP32 logró conectarse al AP, mostramos en pantalla los parámetros de la interfaz de red
            # (dirección IP, máscara de subred, pasarela y servidor DNS)
            print("Wi-Fi Conectado:", wlan.ifconfig()[0])
            wifi_conectado = True
            return True
        else:
            # Si el ESP32 no pudo conectarse al AP, mostramos un mensaje de error
            print("Fallo al conectar Wi-Fi.")
            wifi_conectado = False
            return False
    except Exception as e:
        # Capturamos la excepción y la mostramos en pantalla
        print("Error Wi-Fi:", e)
        wifi_conectado = False
        return False

# Función que desconecta el dispositivo de la red WiFi
def desconectar_wifi():
    global wifi_conectado, mqtt_client
    try:
        # Desconectar MQTT primero si está activo
        if mqtt_client:
            desconectar_mqtt()
        # Creamos una instancia de la clase WLAN y realizamos la desconexión    
        wlan = network.WLAN(network.STA_IF)
        wlan.disconnect()
        wlan.active(False)
    except:
        pass # ===== Falta el manejo de la excepción =====
    wifi_conectado = False
    print("Wi-Fi desconectado.")

# Función que desconecta el dispositivo del broker MQTT
def desconectar_mqtt():
    global mqtt_client
    try:
        # Desconectamos el cliente MQTT del broker
        mqtt_client.disconnect()
    except:
        pass  # ===== Falta el manejo de la excepción =====
    mqtt_client = None
    print("MQTT desconectado.")

# --- NUEVA LÓGICA MQTT (RECIBIR CONFIG Y COMANDOS) ---
# Función callback que se ejecuta al recibir mensajes de los tópicos MQTT
def on_message_mqtt(topic, msg):
    global estado_Carga, estado_Descarga, modo_auto, paso_auto, perfil_actual, bateria_qr_actual, nivelPWM
    global PERFILES_LOCALES, VOLTAJE_CORTE_CARGA, VOLTAJE_CORTE_DESCARGA
    # Fijamos la codificación UTF-8 para los mensajes de los tópicos MQTT
    topic_str = topic.decode('utf-8')  # Nombre del tópico
    payload = msg.decode('utf-8')  # Payload (contenido de los mensajes )
    
    print(f"MQTT RECIBIDO [{topic_str}]: {payload}")
    
    if topic_str == MQTT_TOPIC_CONFIG:  
        # Datos recibidos del tema config_perfil, con formato: V_C:8.4,V_D:6.0
        try:
            # Guardamos los umbrales de tensión en un diccionario, en el cual las claves son los símbolos provenientes del mensaje
            datos = dict(item.split(":") for item in payload.split(","))
            # Convertimos los valores de tensión a float
            VOLTAJE_CORTE_CARGA = float(datos['V_C'])
            VOLTAJE_CORTE_DESCARGA = float(datos['V_D'])
            
            # Buscar perfil correspondiente para mantener sincronizada la pantalla
            perfil_actual = "PERSONALIZADO"
            # Recorremos el diccionario de perfiles y comparamos los umbrales de carga y descarga recibidos del
            # mensaje con los umbrales asignados a cada tipo de batería. Si la diferencia es menor a 0.05 V,
            # registramos el nombre de la nueva batería
            for name, (vc, vd) in PERFILES_LOCALES.items():
                if abs(VOLTAJE_CORTE_CARGA - vc) < 0.05 and abs(VOLTAJE_CORTE_DESCARGA - vd) < 0.05:
                    perfil_actual = name  # Actualizamos el perfil de la batería
                    break
            print(f"Perfil actualizado -> Carga: {VOLTAJE_CORTE_CARGA}V, Descarga: {VOLTAJE_CORTE_DESCARGA}V, Perfil: {perfil_actual}")
        except:
            print("Error parseando perfil")
 
    elif topic_str == MQTT_TOPIC_QR:
        # Datos recibidos del tópico bateria_qr
        # Quitamos los espacios al comienzo y al final del mensaje recibido
        nuevo_qr = payload.strip()
        if nuevo_qr and nuevo_qr != "NINGUNA":
            # Si se recibió un código QR y además es distinto de "NINGUNA", lo actualizamos
            bateria_qr_actual = nuevo_qr
            print(f"QR actualizado desde MQTT: {bateria_qr_actual}")
 
    elif topic_str == MQTT_TOPIC_COMANDOS:
        # Datos recibidos del tópico comandos (órdenes de control para iniciar/detener la carga/descarga)
        # Evaluamos la orden recibida y la ejecutamos, siempre y cuando no se haya recibido un aleta térmica
        if payload == "STOP_ALL":  # Detener todo el sistema
            # Actualizamos el estado del sistema
            modo_auto = False
            paso_auto = "IDLE"
            estado_Carga = False
            estado_Descarga = False
            # Ponemos en 0 el ciclo de actividad de las señales PWM de los pines de carga y descarga para detener
            # la carga o descarga
            pin_Carga.duty(0)
            pin_Descarga.duty(0)
            # Notificamos a la cámara para detener el escaneo si estuviese activo
            uart_cam.write("STOP\n")
        elif not alerta_termica:
            nivelPWM = 0
            if payload in ("START_SCAN", "SCAN"):  # Orden de escaneo remoto recibida desde MQTT
                uart_cam.write("SCAN\n")
                uart_tft.write("SCAN_STATUS:SCANNING\n")
                print("ORDEN DE ESCANEO ENVIADA A LA CÁMARA DESDE MQTT")
            elif payload == "START_C":  # Iniciar carga
                # Actualizamos el estado del sistema
                estado_Carga = True
                estado_Descarga = False
            elif payload == "START_D":  # Iniciar descarga
                estado_Descarga = True
                estado_Carga = False
            elif payload == "START_AUTO":  # Iniciar el modo auto (uno o dos ciclos completos de carga/descarga)
                modo_auto = True
                paso_auto = "DESC1"  # Estado de descarga (DESC1)
                estado_Descarga = True
                estado_Carga = False
                print("MODO AUTO INICIADO DESDE MQTT")

# Función para iniciar la comunicación MQTT
def iniciar_mqtt():
    global mqtt_client
    if not wifi_conectado:
        # Si el dispositivo no está conectado a una red WiFi, no podemos iniciar MQTT
        print("MQTT requiere Wi-Fi.")
        return False
    try:
        # Creamos una instancia de la clase MQTTClient para configurar la comunicación MQTT
        # Le pasamos al constructor el ID del cliente, el IP del broker, el puerto, el usuario y la contraseña
        mqtt_client = MQTTClient(MQTT_CLIENT_ID, MQTT_BROKER, port=MQTT_PORT, user=MQTT_USER, password=MQTT_PASS)
        # Establecemos un callback que se ejecutará cuando se reciban mensajes en los tópicos a los que se suscribe el ESP32 maestro
        mqtt_client.set_callback(on_message_mqtt)
        # Establecemos la conexión con el broker
        mqtt_client.connect()
        # Suscribimos el ESP32 maestro a los tópicos "config_perfil", "comandos" y "bateria_qr"
        mqtt_client.subscribe(MQTT_TOPIC_CONFIG)
        mqtt_client.subscribe(MQTT_TOPIC_COMANDOS)
        mqtt_client.subscribe(MQTT_TOPIC_QR)
        print("MQTT Suscrito a perfiles, comandos y QR.")
        return True
    except Exception as e:
        print("Error iniciando MQTT:", e)
        mqtt_client = None
        return False


# Función que lee la temperatura del NTC y aplica un filtro de ser necesario
def leer_temperatura():
    global temperatura_filtrada, V_REF, K
    # Declaramos constantes para el cálculo de la temperatura
    R_FIJA = 100000.0  # Resistencia que forma un divisor de tensión con el NTC (100k)
    T0 = 298.15  # Temperatura de 25°C (298.15 K)
    BETA_COEF = 3950.0  # Coeficiente beta del termistor
    R0 = 100000.0  # Resistencia del termisor a una temperatura de 25°C
    muestras = []  # Lista que almacena las muestras de temperatura
    for i in range(15):  # Promediamos 15 muestras tomadas cada 1 ms
        adc_val = adc_temp.read()  # Leemos el valor codificado del ADC (entre 0 y 4095)
        # Si el valor codificado está por debajo de 100 o por encima de 3995, lo descartamos
        if adc_val <= 100 or adc_val >= 3995: continue # Descartar picos/ruido extremo
        # Obtenemos la tensión sobre el termistor NTC, para lo cual debemos obtener primero la
        # tensión que muestrea el ADC, que es la tensión sobre el NTC con una atenuación de 12 dB
        v_ntc = (V_REF / K) * (adc_val / 4095.0)  # Tensión en mV
        # Calculamos la resistencia del NTC
        r_ntc = v_ntc * R_FIJA / (3300 - v_ntc)
        # Evitar logaritmo de cero o valores negativos
        if r_ntc <= 0: continue
        # Calculamos la temperatura en K a partir de la siguiente fórmula:
        # r_ntc = R0*e^(BETA*(1/temp_k - 1/T0))
        # temp_k = 1 / (1/T0 + 1/BETA * log(r_ntc/R0))
        temp_k = 1.0 / (1.0 / T0 + 1.0 / BETA_COEF * math.log(r_ntc / R0))
        # Guardamos el valor de temperatura en °C en la lista de muestras
        muestras.append(temp_k - 273.15)
        sleep(0.001)  # Demora de 1 ms
    
    if not muestras:
        # Si no se tomaron muestras, retornamos el valor anterior de temperatura, siempre y cuando 
        # esté definido; de lo contrario, retornamos un valor de -99°C (valor ficticio)
        return temperatura_filtrada if temperatura_filtrada is not None else -99.0
    # Calculamos la temperatura promedio
    raw_temp = sum(muestras) / len(muestras)
    
    # Filtro de Media Móvil Exponencial (EMA)
    if temperatura_filtrada is None:
        temperatura_filtrada = raw_temp
    else:
        alpha = 0.08 # Factor de suavizado (0.08 da alta estabilidad sin retrasar de más)
        temperatura_filtrada = (alpha * raw_temp) + ((1.0 - alpha) * temperatura_filtrada)
        
    return temperatura_filtrada
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

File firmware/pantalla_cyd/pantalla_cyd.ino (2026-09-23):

#include <SPI.h>
#include <TFT_eSPI.h>  // Biblioteca para manejar la comunicación con la pantalla TFT
#include <lvgl.h>  // Biblioteca para crear una interfaz de usuario en el display
#include <ArduinoJson.h>  // Biblioteca para trabajar con archivos JSON
#include <XPT2046_Touchscreen.h>  // Biblioteca para gestionar la comunicación con el sensor táctil de la pantalla (touchscreen)
#include "ui.h" // Biblioteca que implementa la interfaz de usuario en el display

// Pines de comunicación con el Master (Conector CN1 libre de interferencias)
#define RXD2 22  // Pin RXD del UART2 del ESP32-CYD (pin TXD del UART2 del ESP32 maestro)
#define TXD2 27  // Pin TXD del UART2 del ESP32-CYD (pin RXD del UART2 del ESP32 maestro)

// Pines del chip táctil XPT2046 (CYD Versión R)
#define XPT2046_MOSI 32  // Pin MOSI (GPIO32)
#define XPT2046_MISO 39  // Pin MISO (GPIO39)
#define XPT2046_CLK 25  // Pin CLK (GPIO25)
#define XPT2046_CS 33  // Pin CS (GPIO33)
// Pin del led trasero (backlight)
#define BACKLIGHT_PIN 21  // Pin del LED trasero (backlight) GPIO21 (GPIO22 es RXD2 de CN1)

// Instancias de Hardware
// Creamos una instancia de la clase TFT_eSPI
TFT_eSPI tft;  
// Creamos una instancia aparte de la clase SPI para manejar la comunicación con el chip táctil, ya que el objeto SPI que
// está declarado dentro de la biblioteca tiene acceso al bus VSPI, el cual se conecta a la pantalla TFT. En este caso,
// creamos un objeto que accede al bus HSPI, ya que el controlador XPT2046 está conectado a pines diferentes
SPIClass mySpi(HSPI); // Bus SPI aislado para el táctil
// Creamos una instancia de la clase XPT2046_Touchscreen, pasándole como argumento el pin CS del bus SPI al cual se conecta el XPT2046
XPT2046_Touchscreen ts(XPT2046_CS); // Modo Polling

// Buffer de memoria para el motor gráfico LVGL
static const uint16_t screenWidth  = 320;  // Ancho de la pantalla
static const uint16_t screenHeight = 240;  // Alto de la pantalla
// Declaramos un buffer que almacena los colores de cada píxel para un tamaño de pantalla de 1/10
static lv_color_t buf[screenWidth * screenHeight / 10];  

// Variables globales para los controladores en LVGL v8
// Variable que contiene buffers de gráficos internos llamados buffers de dibujo (draw buffers)
static lv_disp_draw_buf_t draw_buf;  
// Descriptor del driver del display. Esta variable contiene funciones callback para interactuar con el display y manipular
// elementos de dibujo asociados
static lv_disp_drv_t disp_drv;
// Descriptor del driver de un dispositivo de entrada (por ejemplo un touchpad)
static lv_indev_drv_t indev_drv;  

// ==========================================
// --- DRIVERS DE LVGL (API v8) ---
// ==========================================

// ======= FUNCIONES CALLBACK ASOCIADAS A LOS DESCRIPTORES DE LOS DRIVERS DE LVGL =======
// 1. Envío de píxeles a la pantalla (LVGL v8)
// Esta función copia una imagen renderizada a un área del display
void my_disp_flush(lv_disp_drv_t *disp, const lv_area_t *area, lv_color_t *color_p) {
  uint32_t w = (area->x2 - area->x1 + 1);
  uint32_t h = (area->y2 - area->y1 + 1);
  tft.startWrite();
  tft.setAddrWindow(area->x1, area->y1, w, h);
  tft.pushColors((uint16_t *)&color_p->full, w * h, true);
  tft.endWrite();
  lv_disp_flush_ready(disp);
}

// 2. Lectura del panel táctil (LVGL v8)
// Función que lee un dispositivo de entrada (en este caso, un panel táctil)
void my_touchpad_read(lv_indev_drv_t * indev, lv_indev_data_t * data) {
  if (ts.touched()) {
    TS_Point p = ts.getPoint();
    data->state = LV_INDEV_STATE_PR; 
    
    // Mapeo crudo -> píxeles
    data->point.x = map(p.x, 200, 3700, 0, screenWidth);
    data->point.y = map(p.y, 240, 3800, 0, screenHeight);
  } else {
    data->state = LV_INDEV_STATE_REL;
  }
}

// ==========================================
// --- ACCIONES DE LA INTERFAZ (Botones) ---
// ==========================================
// Ahora todas las órdenes salen por el Serial2 (Pines del CN1)
// Todas estas funciones envían comandos al ESP32 maestro a través del UART2 (que es el mismo número de UART que usa el otro ESP32 para recibir los comandos)
void accion_iniciar_carga() { Serial2.print("START_C\n"); }  // Envía el comando de inicio de carga 
void accion_iniciar_descarga() { Serial2.print("START_D\n"); }  // Envía el comando de inicio de descarga
void accion_parar_todo() { Serial2.print("STOP_ALL\n"); }  // Envía el comando de parada

// Acción para solicitar el escaneo de código QR a la ESP32-CAM a través del Master
void accion_escanear_qr() {
  Serial2.print("START_SCAN\n");
  lv_textarea_set_text(ta_main_qr, "Escaneando...");
  lv_obj_set_style_text_color(ta_main_qr, lv_color_hex(0x38bdf8), 0);  // Color celeste indicando escaneo activo
}

// Función que guarda la configuración de acuerdo a lo ingresado por el usuario en la pantalla
void accion_guardar_config() {
  // Obtenemos el texto de las áreas de texto correspondientes a las credenciales WiFi y MQTT
  String ssid = lv_textarea_get_text(ta_ssid);
  String pass = lv_textarea_get_text(ta_pass);
  String mqtt = lv_textarea_get_text(ta_mqtt);
  String muser = lv_textarea_get_text(ta_mqtt_user);
  String mpass = lv_textarea_get_text(ta_mqtt_pass);
  // Enviamos el comando "SET_WIFI" al ESP32 maestro a través del UART2 junto con las credenciales
  Serial2.print("SET_WIFI:");
  Serial2.print(ssid); Serial2.print(",");
  Serial2.print(pass); Serial2.print(",");
  Serial2.print(mqtt); Serial2.print(",");
  Serial2.print(muser); Serial2.print(",");
  Serial2.print(mpass);
  Serial2.print("\n");
}

void accion_guardar_limites() {
  // Obtenemos el texto de las áreas de texto correspondientes a los límites de corriente y tensión
  String corte_c = lv_textarea_get_text(ta_corte_carga);
  String corte_d = lv_textarea_get_text(ta_corte_descarga);
  String corr_lim = lv_textarea_get_text(ta_corriente_lim);
  // Enviamos el comando "SET_LIMITS" al ESP32 maestro a través del UART2 junto con los límites
  Serial2.print("SET_LIMITS:");
  Serial2.print(corte_c); Serial2.print(",");
  Serial2.print(corte_d); Serial2.print(",");
  Serial2.print(corr_lim);
  Serial2.print("\n");
}

// --- CALLBACKS INTERACTIVOS DE BATERÍA ---
bool is_updating_from_uart = false;  // Variable que indica si se está actualizando la pantalla con los datos recibidos por UART
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

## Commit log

2026-09-16 Primer commit
    [BOM_Cargador_Baterias.xlsx, Cuerpo1.3mf, PCB cargador con pantalla.dsn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]
2026-09-23 Integración de lector QR serie por hardware, botón SCAN en pantalla y optimización del backend preservando comentarios
2026-10-01 Se agregó un .gitignore para dejar de rastrear ciertos archivos
2026-10-16 Se movieron los estilos y el script a archivos aparte, y se hicieron cambios menores a la interfaz
2026-10-16 Se modificó la lectura del ADC para obtener la tensión de la batería y la temperatura
2026-10-16 Se forzó a 0 la tensión y la corriente cuando toman valores muy bajos
2026-10-21 Calibración y estabilización de potencia, filtrado INA219/EMA, control PWM adaptativo y mejoras en UI
2026-10-22 Filtro EMA optimizado (alpha=0.06), 50 muestras de sobremuestreo y filtrado de corriente para eliminar ruido de +-30mV
2026-10-22 Eliminar ajuste sintético proporcional a corriente para evitar distorsión y aplicar calibración estática de -20mV
2026-10-22 Compensar caída física en cables de 155 mOhm (140 mV a 900 mA) en fase para Carga y Descarga
2026-10-22 Ajustar factor de compensación de carga a 0.000205 para eliminar desvío residual de 45 mV
2026-10-23 Se cambió el factor de compensación de la tensión a partir de las resistencias de los cables banana-coco medidas con el multímetro
2026-10-27 Se hicieron modificaciones en el panel izquierdo, se agregó la función para cambiar el perfil, se cambió el título y se aumentó la altura de los gráficos
2026-10-27 Se hicieron pequeñas modificaciones para recibir el perfil de batería de la interfaz
2026-10-28 Se agregó la opción de cancelar el escaneo de la batería desde la interfaz, quitando el timeout de 30s para escanear con la cámara
2026-10-28 Se volvió a poner el timeout para el escaneo del QR
2026-10-30 Se corrigieron pequeños detalles en la tabla de historial y en la pantalla de escaneo
